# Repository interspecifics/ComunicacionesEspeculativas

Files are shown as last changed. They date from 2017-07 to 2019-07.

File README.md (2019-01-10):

# ComunicacionesEspeculativas
Es un proyecto basado en una máquina que es capaz de observar y aprender de
microorganismos para crear un score audiovisual a partir de los patrones que encuentre en su comportamiento. Este proyecto se apoya en la creación de una inteligencia artificial, la cual reconoce comportamientos organizados reiterativos en cultivos biológicos y los transforma en eventos que dota de una gestualidad audiovisual específica con el fin de lograr una composición autogenerativa que responde a las lógicas de decisión que esta inteligencia construye con el tiempo. 

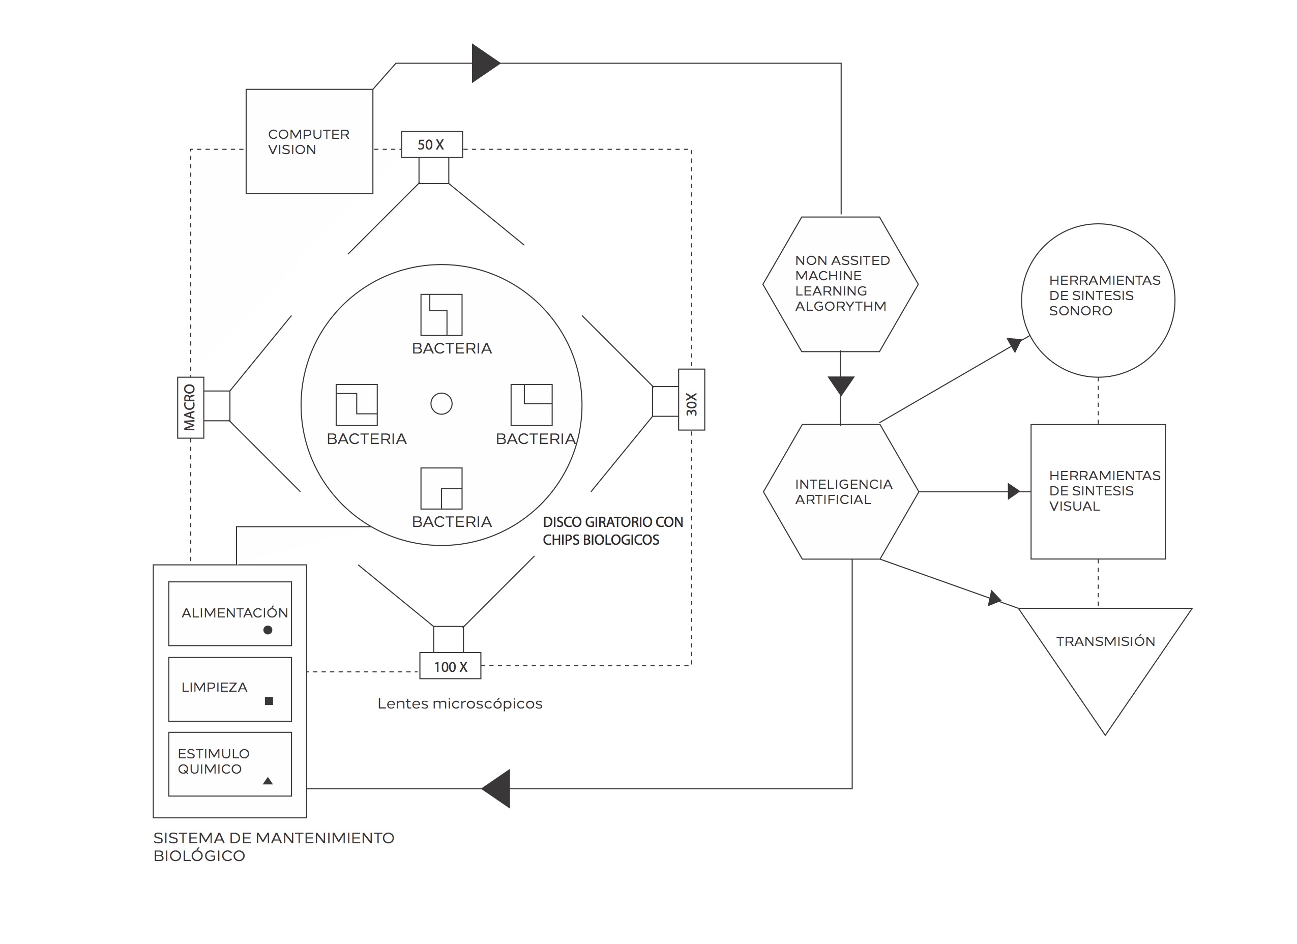
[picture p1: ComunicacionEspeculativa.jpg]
the system


## Instalación CV2.4.9 en Mac
1 - Instalar brew http://brew.sh/

>brew tap homebrew/science

>brew install opencv

## Instalación CV2 en la raspberry

seguir el tutorial que se encuentra aquí:
https://www.pyimagesearch.com/2015/02/23/install-opencv-and-python-on-your-raspberry-pi-2-and-b/

## Instalación netatalk

1- Installation:

>sudo apt-get update

>sudo apt-get install netatalk

2- Configuration

**Stop the service:**

>sudo /etc/init.d/netatalk stop

**Open the configuration file:**

>sudo nano /etc/netatalk/AppleVolumes.default

**You can edit the mount folder if you wish or leave the default value:**

>~/ "Home Directory"

**Start the service again**

>sudo /etc/init.d/netatalk start

## Configurar USB como storage local

**1 - To mount a USB drive:**

>sudo mkdir /mnt/usbdrive

>sudo mount /dev/sda1 /mnt/usbdrive

>ls /mnt/usbdrive

**2 - To list your file systems:**

>sudo fdisk -l

>sudo mount -l

>df -h

**3- Before disconnecting a USB drive:**

>sudo umount /dev/sda1

**4- Format a drive to EXT4**

>sudo mkfs.ext4 /dev/sda1 -L untitled

**5- Create a mount point**

>sudo mkdir /mnt/usbdrive

**6- Check the dev directory

>/dev/sd*

**7- To mount the drive to your mount point ‘usbdrive‘.

>sudo mount /dev/sda1 /mnt/usbdrive

**8- Disconnect / Unmount A Drive**

>sudo umount /dev/sda1

## Biotracker XY

Para la construcción de biotracker xy es necesario la impresión de la piezas que se encuentran aquí :

https://github.com/interspecifics/ComunicacionesEspeculativas/tree/master/Impresion%203d%20XY

Biotracker

Biotracker

## Controllers 

Actualmente existe dos placas electronicas para el control de los dos dispositivos disponibles el Microscopio Z y el Biotracker X/Y

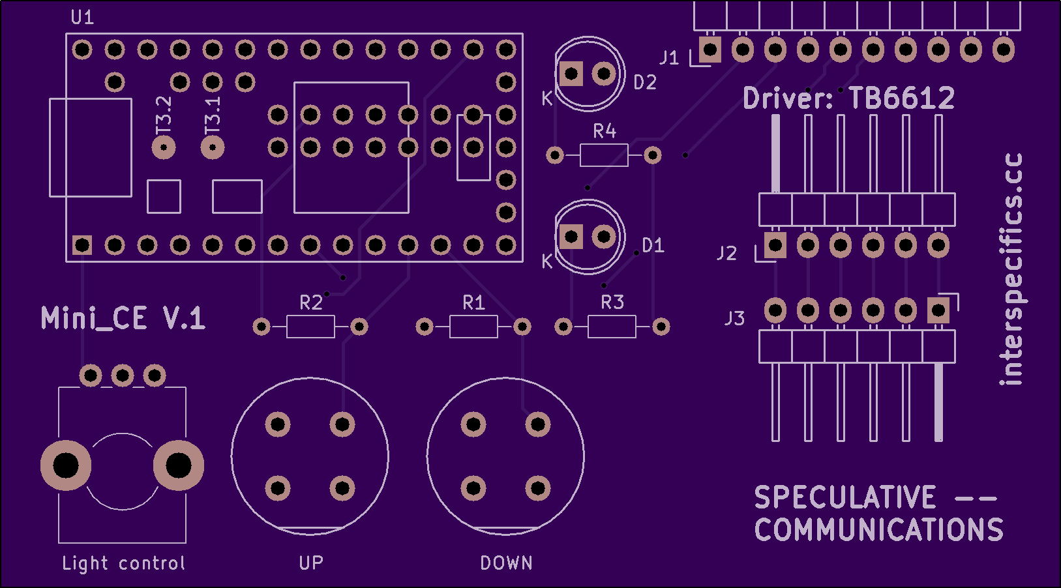
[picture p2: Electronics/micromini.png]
microminiz


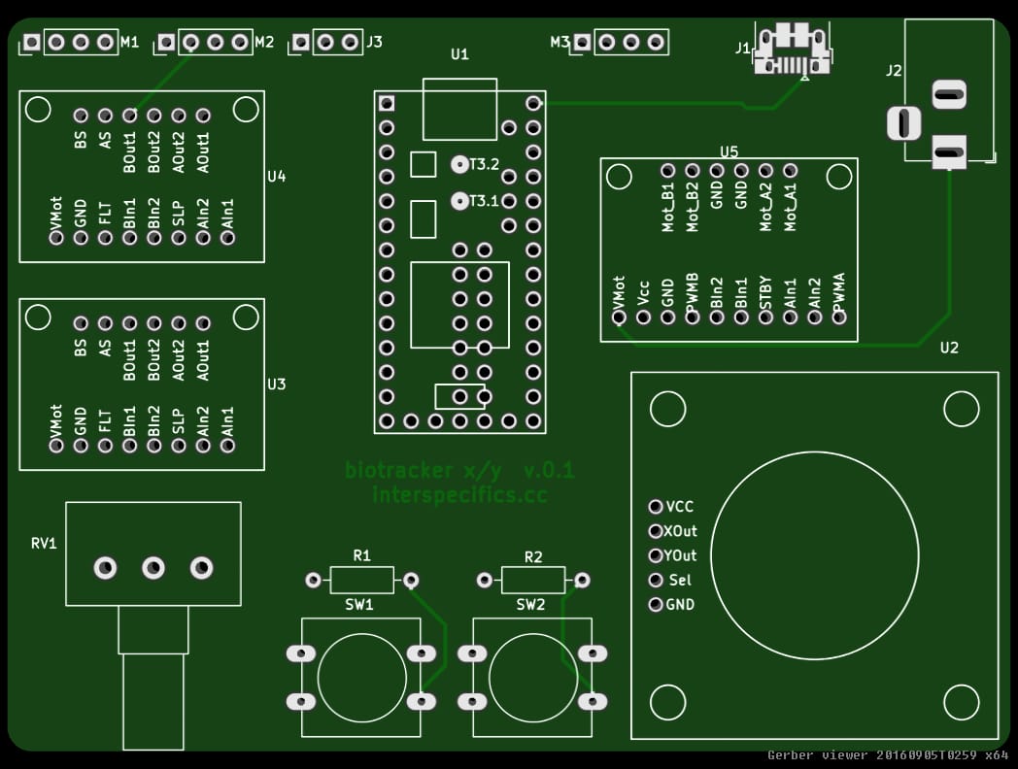
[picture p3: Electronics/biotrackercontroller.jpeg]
Biotracker Controller


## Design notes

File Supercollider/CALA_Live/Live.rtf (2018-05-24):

1. Drone
2. Multidrone
3. Saturn cluster Loop Flutes con noise//TUBES
4. Toplogical sonando los que están arriba
5. Saturno grande lead flute
6. Free swimmers
7. Big bass
8. Infinite energy
9. Saturn cluster Loop Flutes con harmonic
10. Collision detected
11. Salir
Luz cristal off

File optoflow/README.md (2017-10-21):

# CE_probe

====================================================================

# Para usar la pycam como cv2.videoCapture(0) hay que ejecutar

sudo apt-get install autoconf gettext libtool libjpeg62-dev

sudo apt-get install autoconf

sudo apt-get install v4l-utils

sudo modprobe bcm2835-v4l2

# Cambiar resolucion para hacer una captura [parece que no se mantiene]

v4l2-ctl --set-fmt-video=width=1920,height=1080,pixelformat=3

v4l2-ctl --stream-mmap=3 --stream-count=1 --stream-to=test1.jpg

# Llamar la herramienta desde otro proceso

import subprocess

subprocess.Popen(" python ce_ff_02.py -v \"0\" -s \"False\" -w \"False\"", shell=True)

# Ejecutar con distintias opciones

>python ce_ff_06.py -v "./TL6.mp4" -w "False" -s "True" -c "True"

>python ce_ff_06.py -v "./TL9.mp4" -w "True" -s "True" -c "False" -o "./TL9_out"

>python ce_ff_06.py -v "./videos/TL13.mp4" -w "False" -s "True" -n "True" -c "True"

>python ce_ff_07.py -v "./TL3.mp4" -w "False" -s "False" -n "True" -c "True" -d "True" -r "192.168.1.25" -p "57120"

====================================================================

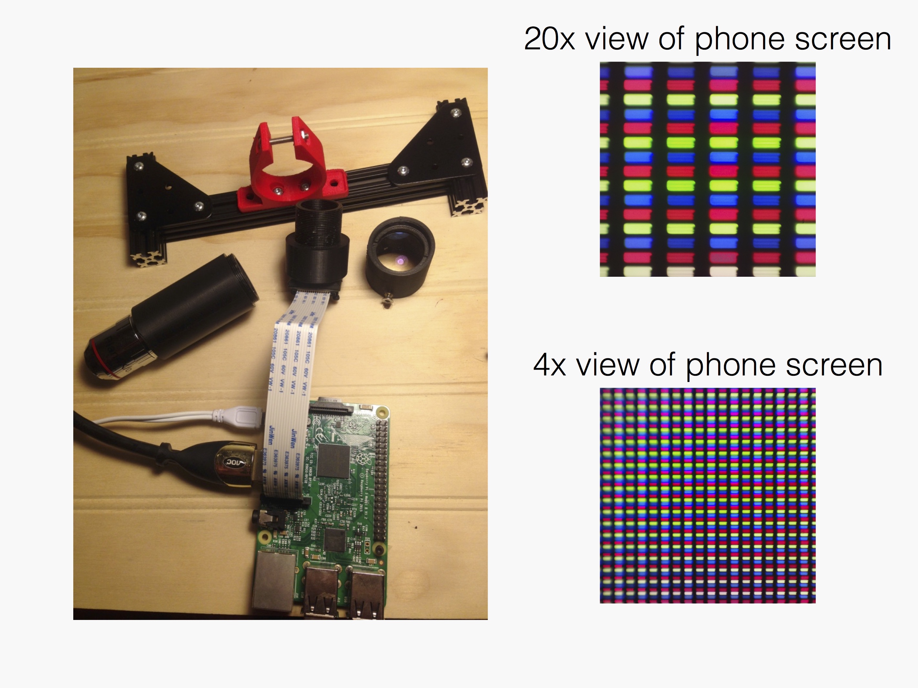
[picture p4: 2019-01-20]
3D_files/CE_optics/optical tube 2 fig.jpg

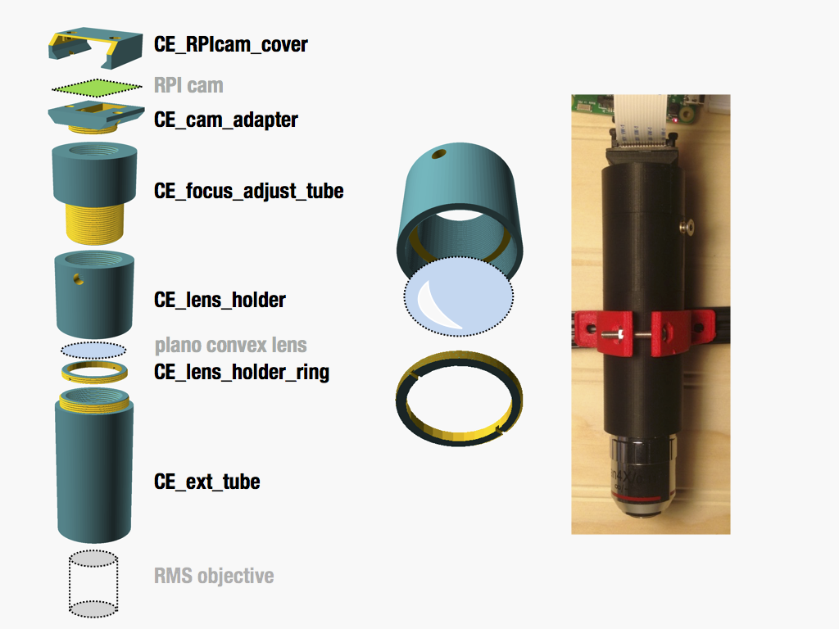
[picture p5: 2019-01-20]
3D_files/CE_optics/optical tube fig.png

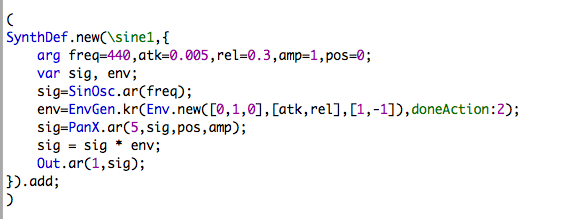
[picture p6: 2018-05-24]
Supercollider/CALA_Live/Screen Shot 2018-05-01 at 9.21.22 AM.png

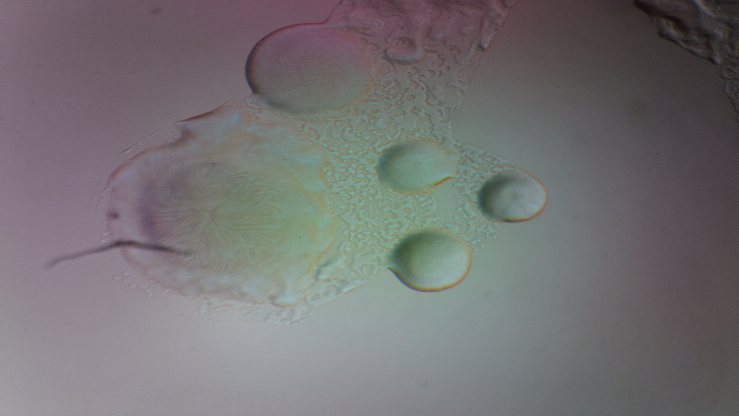
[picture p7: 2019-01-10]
Dataservice/CE_server/v05.png

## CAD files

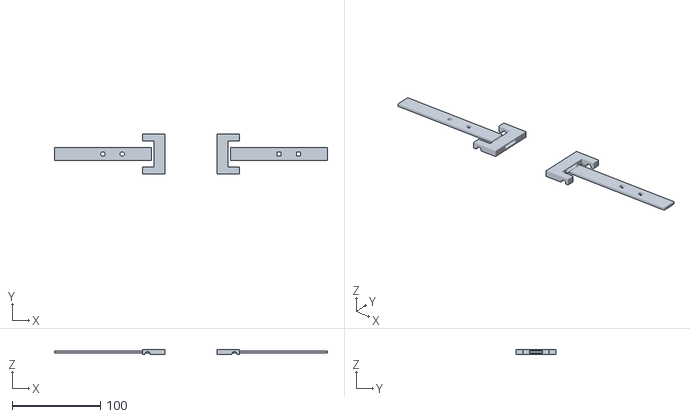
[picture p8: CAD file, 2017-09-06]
3D_files/CE_LEDholderV2.stl
310.0 x 45.0 x 6.00

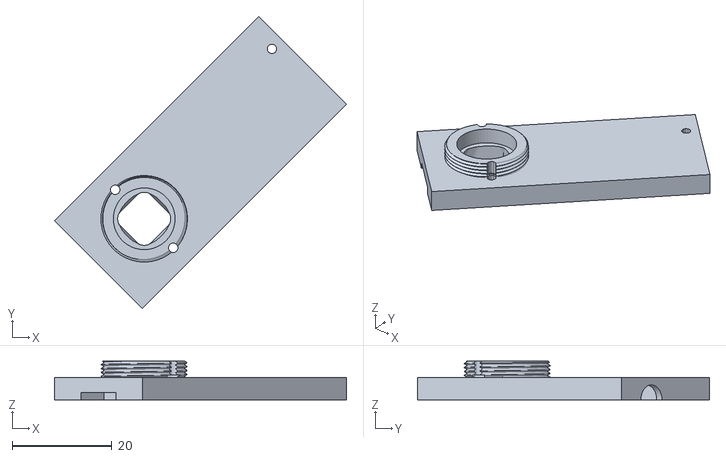
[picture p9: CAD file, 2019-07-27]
3D_files/CE_optics/CE_c270_camera_adapter.stl
58.7 x 58.7 x 7.78

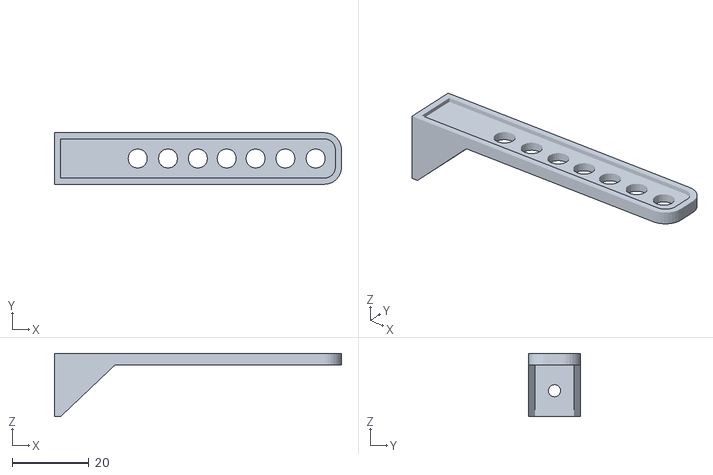
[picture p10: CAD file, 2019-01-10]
Impresion 3d XY/Fijacion LED/LED Inferior soporte horizontal.stl
75.0 x 13.5 x 16.5

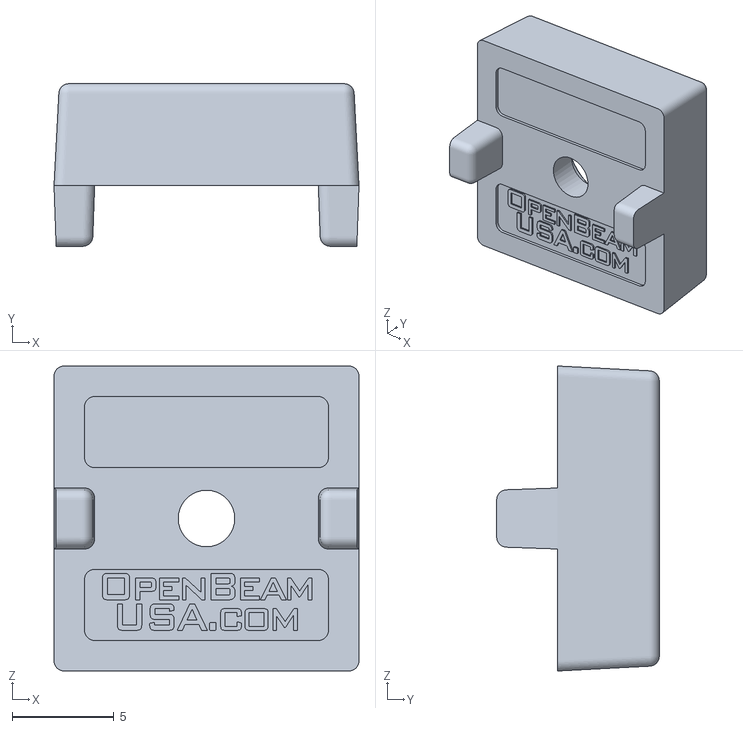
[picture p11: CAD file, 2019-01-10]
Impresion 3d XY/OpenBeam/Feet.STL
15.0 x 8.00 x 15.0

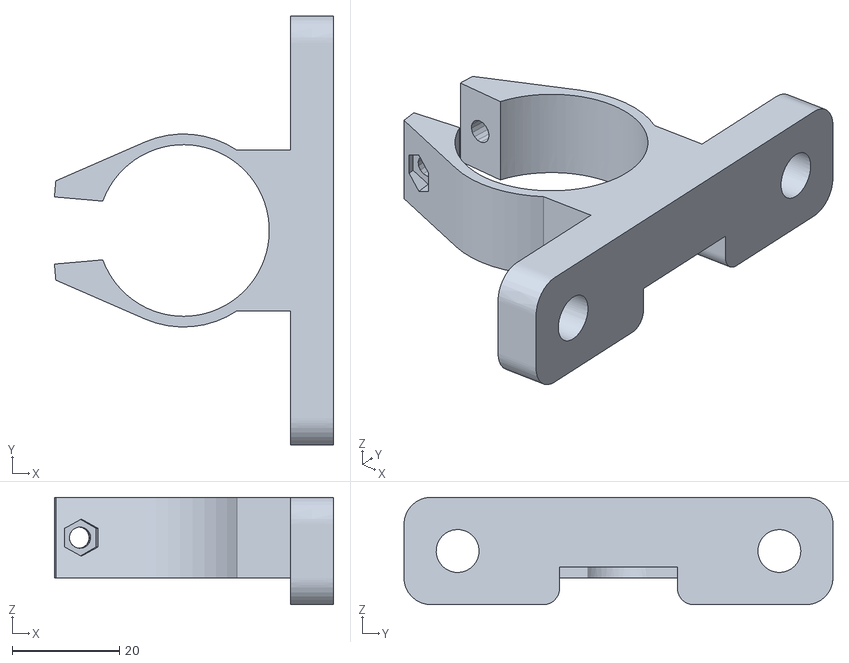
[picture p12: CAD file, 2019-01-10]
Impresion 3d XY/XY/Eje Y lente.stl
52.1 x 80.0 x 20.0

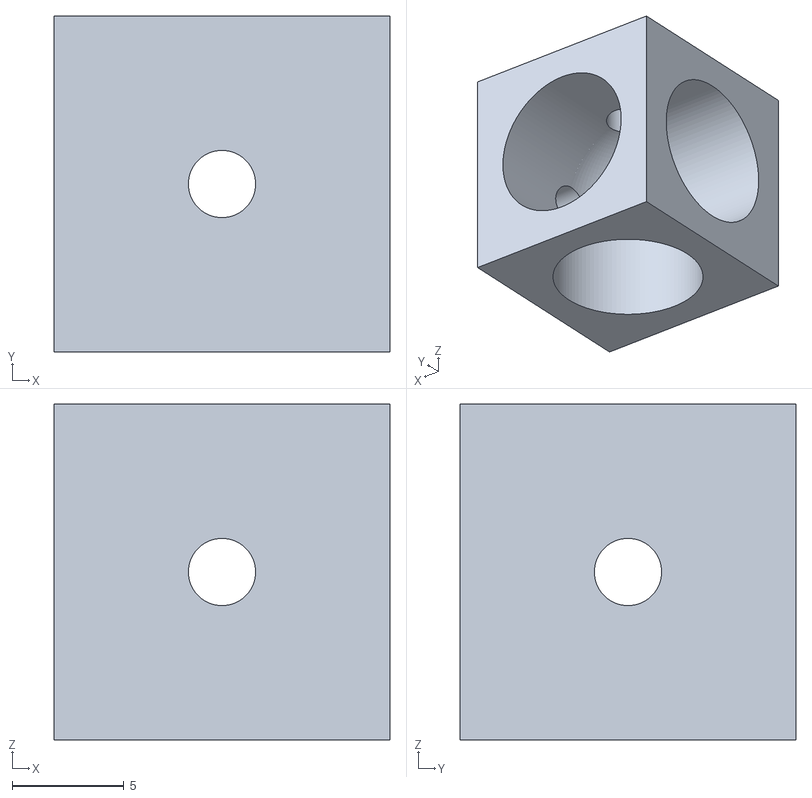
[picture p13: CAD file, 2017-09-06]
3D_files/CE_corner_openbeam.stl
15.0 x 15.0 x 15.0

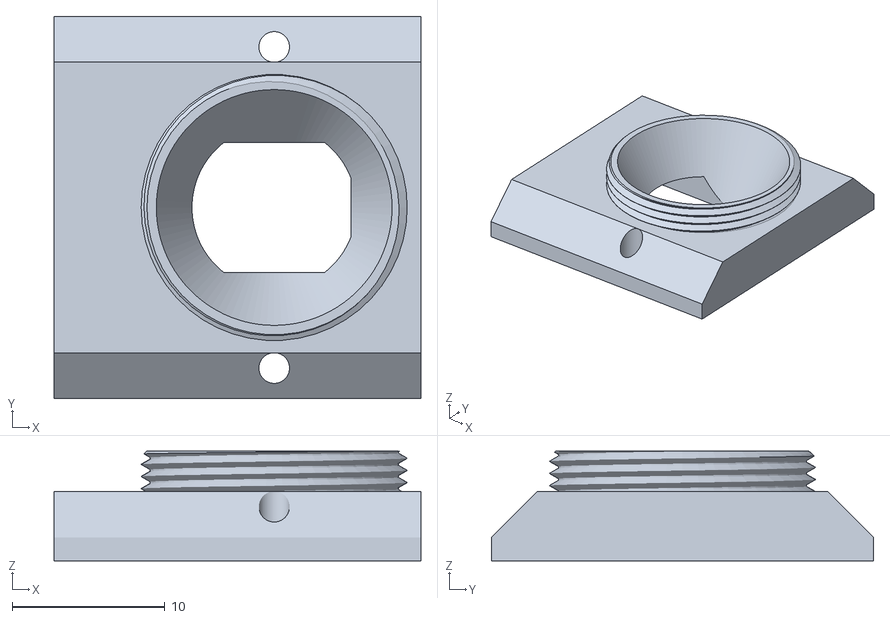
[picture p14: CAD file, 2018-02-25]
3D_files/CE_optics/CE_cam_adapter.stl
24.0 x 25.0 x 7.19

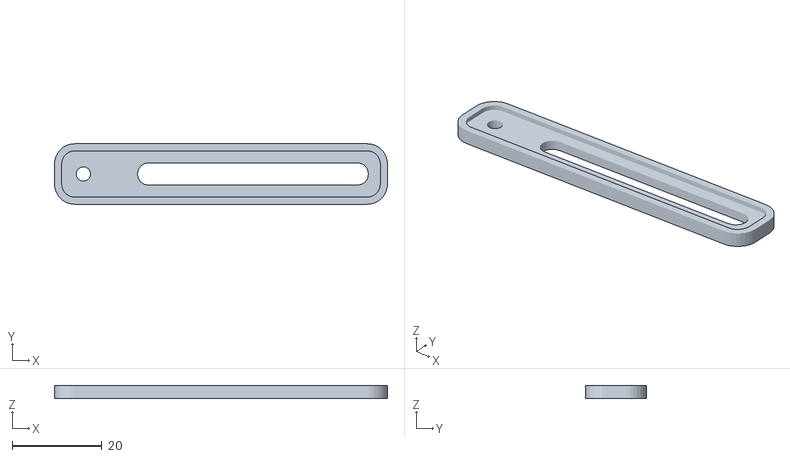
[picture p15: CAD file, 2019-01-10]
Impresion 3d XY/Fijacion LED/LED inferior fijacion vertical.stl
74.2 x 13.5 x 3.00

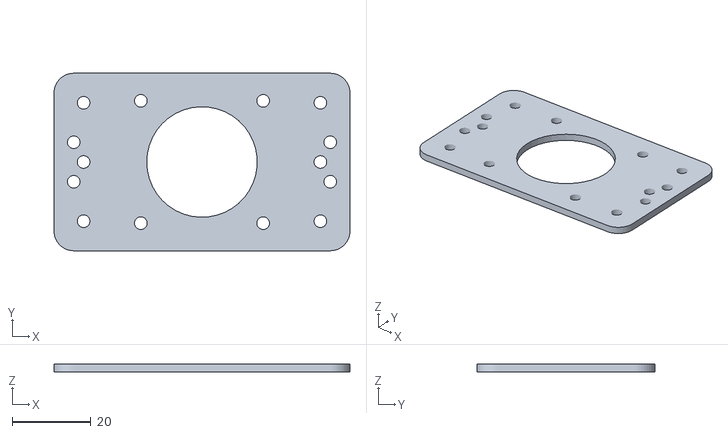
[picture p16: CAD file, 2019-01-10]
Impresion 3d XY/OpenBeam/NEMA_17_Motor_Mount.STL
75.0 x 45.0 x 2.03

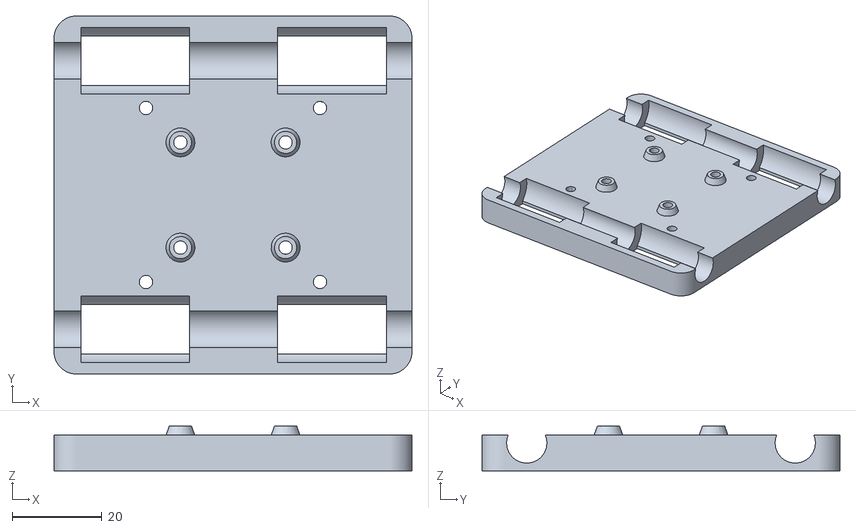
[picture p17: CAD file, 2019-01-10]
Impresion 3d XY/XY/Base inferior.stl
80.0 x 80.0 x 10.0

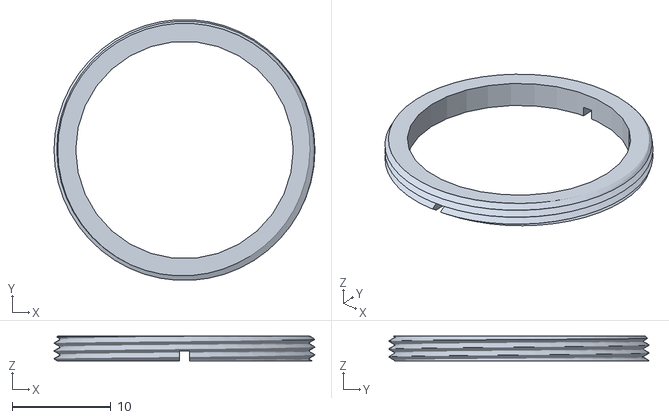
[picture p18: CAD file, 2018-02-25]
3D_files/CE_optics/CE_lens_holder_ring.stl
26.4 x 26.3 x 2.50

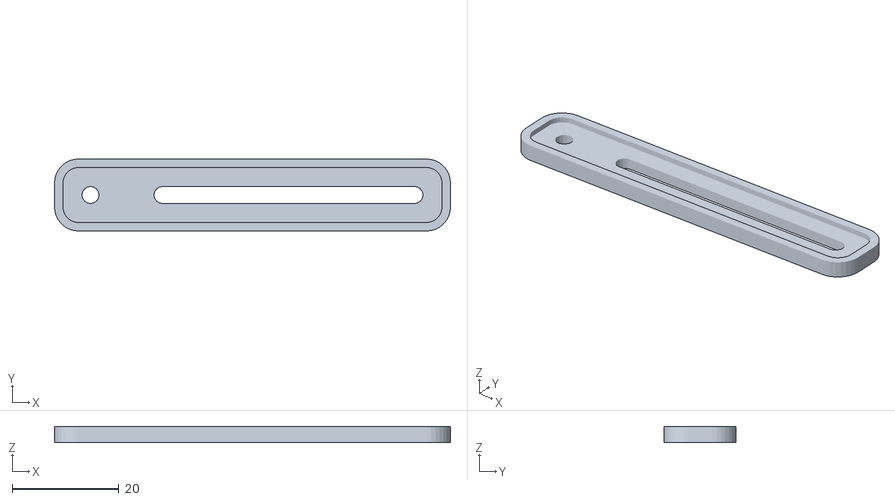
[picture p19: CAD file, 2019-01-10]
Impresion 3d XY/Fijacion LED/LED lateral.stl
74.2 x 13.5 x 3.00

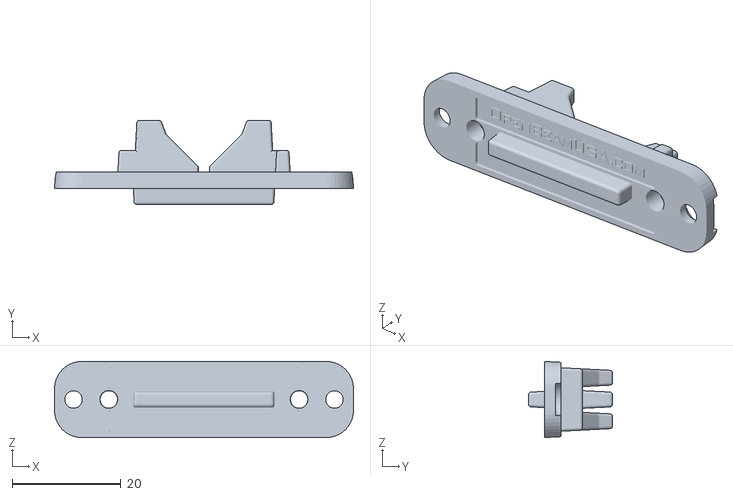
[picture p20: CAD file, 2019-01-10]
Impresion 3d XY/OpenBeam/Shaft Clamp.STL
55.0 x 15.5 x 14.0

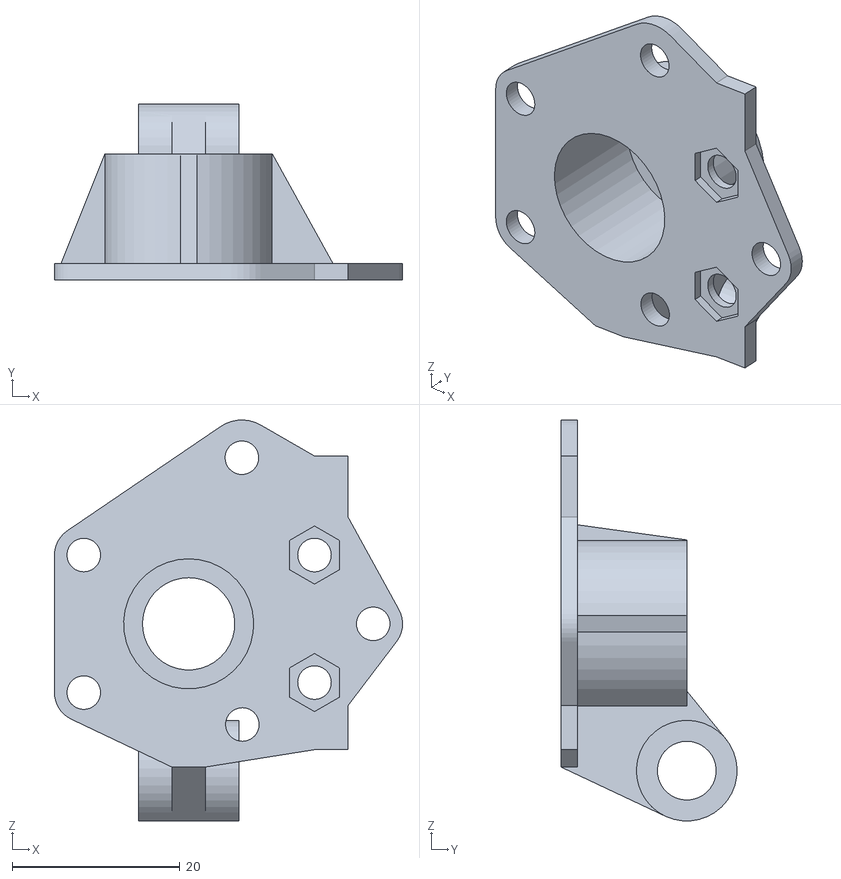
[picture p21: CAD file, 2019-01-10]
Impresion 3d XY/Stage/Bearing Mount Left Top.STL
41.5 x 21.0 x 47.8

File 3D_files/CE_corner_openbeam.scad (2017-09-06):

/*
 Basic corner piece for open beam by Comunicaciones Especulativas 2017 (CC BY 4.0; https://creativecommons.org/licenses/by/4.0/) 
 http://interspecifics.cc/comunicacionesespeculativas/
 
 To use/modify this in your own projects add the following lines to your code:
 use <path_to_this_file/CE_corner_openbeam.scad>
 OB_corner(dim);
 */

// only change dimensions here
OB_corner(3); //2 for 2D joint and 3 for 3D joint
 
// module
beam=15;
screw=3;
$fn=100;
fudge=0.05; // to fix error in rendering leaving thin wall...help me if you better!
dim=3; //2 for 2D joint and 3 for 3D joint
module OB_corner(dim) {
    difference() {
    cube(beam, center=true);
        sphere(r=(beam/2)*0.7, center=true);
            if(dim>2)
                for(i = [ [0,0,0],[90,0,0],[0,90,0]]){
                rotate(i)
                    union() {
                        cylinder(r=screw/2,h=(beam/2)+fudge);
                            translate([0,0,-(beam/2+fudge)]) 
                                cylinder(r=(beam/2)*0.7,h=beam/2);}}
            else
                for(i = [ [0,0,0],[90,0,0]]) {
                 rotate(i)
                    union() {
                        cylinder(r=screw/2,h=(beam/2)+fudge);
                            translate([0,0,-(beam/2+fudge)]) 
                                cylinder(r=(beam/2)*0.7,h=beam/2);}}
                            
    }
}

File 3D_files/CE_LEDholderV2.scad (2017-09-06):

/*
 LED holder for microscope by Comunicaciones Especulativas 2017 (CC BY 4.0; https://creativecommons.org/licenses/by/4.0/) 
 http://interspecifics.cc/comunicacionesespeculativas/
 
 To use/modify this in your own projects add the following lines to your code:
 use <path_to_this_file/CE_LEDholderV2.scad>
 holder(); 
 central();
 */

dist_bars=102;// distance between horizontal stage bars
threaded_bar=5.7;//thickness of horizontal stage bars
LED=5; // standard 5mm LED
width=30;
length=110;// length of the central bar holding the LED
thickness=3;
fit=0.5; // to play with printing resolution and make pieces fit nicely
ADA=4.6; // adafruit LED
hole_style= 2; // 0= normal LED, 1= Adafruit square single RGB LED; 2=both

module holder() { // holders to stage rods
    
difference() {
    cube([length,width*1.5,thickness*2], center=true);
             union() color("Yellow") {
                 cube([length-width*1.7,width*1.5,thickness*2], center=true);
                 cube([length*0.85,width/2,thickness], center=true);
             }
    
    rotate([90,0,0]) color("Red"){
        translate([(length/2-threaded_bar),-(thickness*0.8),-(width*1.5)/2]) {
                cylinder(r=threaded_bar/2,h=width*1.5, $fn=100);  
    }
}
    
    rotate([90,0,0]) color("Blue"){
        translate([-(length/2-threaded_bar),-(thickness*0.8),-(width*1.5)/2]) {
                cylinder(r=threaded_bar/2,h=width*1.5, $fn=100);  
    }
}
    translate([(length/2)-threaded_bar,0,0]) color("Green"){
    cube([width/2,width,thickness*2], center=true);
}
    translate([-((length/2)-threaded_bar),0,0]) color("Red"){
    cube([width/2,width,thickness*2], center=true);
}
}
}

module CentralLED() { // for normal LED
    difference() {
    cube([length,(width/2)-fit,thickness-fit], center=true);
            translate([0,0,-thickness*2]) 
               cylinder(r=LED/2,h=thickness*3, $fn=100);
        translate([length*0.2,0,-thickness*2]) 
               cylinder(r=LED/2,h=thickness*3, $fn=100);
    }
} 

module CentralADA() { //for Adafruit RGB square single LED
    difference() {
    cube([length,(width/2)-fit,thickness-fit], center=true);
               cube([ADA,ADA,ADA], center=true);
         translate([length*0.2,0,0]) 
              cube([ADA,ADA,ADA], center=true);
}
}

module central(){
    if(hole_style == 0) {
			translate([-100,0,0]) { CentralLED();} //normal LED
	} else if(hole_style == 1) {
			translate([100,0,0]) { CentralADA();} //Adafruit square LED
	}
        else if(hole_style == 2) {
			translate([100,0,0]) { CentralADA(); } translate([-100,0,0])  CentralLED();} // print both 
    }

holder(); 
central();


	
        
        

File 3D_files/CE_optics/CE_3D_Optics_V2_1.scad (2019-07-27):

/*
This is part of the project Comunicaciones Especulativas: http://interspecifics.cc/comunicacionesespeculativas/ and https://osf.io/c542q/

This file creates a 3D printed version of the optical pieces used by Alexandre Kabla and his team for the openlabtools microscope (http://openlabtools.eng.cam.ac.uk/Instruments/Microscope/Optics/)
We used:

1- <picam_2_push_fit.scad> from  OpenFlexure Microscope: Raspberry Pi Camera v2 push-fit mount (c) Richard Bowman, January 2016 Released under the CERN Open Hardware License  

2- <threads.scad> from http://dkprojects.net/openscad-threads/

    english_thread is in inches that´s why all mmm values are divided by 25,4

    Normally one male thread fitting into another (e.g. housing a lens)  requires some extra mm in between. Normally this is done by reducing male by 3*corr (corr= 0.2mm). The only exception is at joints where an outsourced piece is hosted (e.g. lens). In this case, the corr is applied to the female.

All this code is licensed under the Creative Commons - Attribution  (CC BY 3.0)
Fernán Federici 2017

*/

use <threads.scad>
use <logitech_c270.scad>
include <picam_2_push_fit.scad>         




corr=0.2;// sometimes used for printing imperfections
sunny_space=6;
wall=2.5;
base_xy=16;
screw_d=21;//distance between screw holes
screw_r=2/2;
screw_hold_r=2;
M12_r=12/2;
mount_h = 10;
int_r=22/2;// internal r of cylinder according to edmund optics
RMS_r=(0.8*25.4)/2; //10,16 mmm of r for DIN (and JIS) objectives that uses RMS, this is about 20.3mm (with thread step of about 0.7mm).
tube_r=29.85/2;//external size
c_mount_r=25.4/2; //for 1 inch standard C-mount diameter
internal_lens_hol=26; //where the Comar lens stays
RMS_mount_h=6; 
c_mount_h=4;
M27_r=27/2; //M27 threads
lens_holder_male_len=3.5; //length of male cylinder end that goes inside top part and holds the lens against the notch of top part 
focus_reg_len=19;// thread for focus adjustment
M3_brass_push_h=4;//for M3 screws
M3_brass_push_w=4;//for M3 screws
tot_len_top=15+5+10+11.3+4;//total len of a single piece A
ext_bot_len=11.3+10+5;
aper_int_h=22.5; //h of internal space 
foc_adj_r=21.5/2;//width of thread for focus control
int_focal_corr_h=16;//total length to adjust focus without crashing to lens of top bottom piece
int_focal_corr_r=18/2;
lens_holder_pos=8.5; //distance of lens holder notch from bottom end of top part 
tot_len_focus_adjust_tube=4+15+16;//16mm to not crash the lens inside the top bottom part
tot_len_bottom=6+40+5;//total length of the ext_tube section
fluo_top_h=26;
pol_ring_h=10;
fluo_bottom_h=25;//ext_fluo_bottom height
sens_x=8.5;
filter_cube_x=40;
filter_cube_y=40;
filter_cube_z=24;
x_triangle=19;//to have hipotenuse of >25
y_triangle=19;//to have hipotenuse of >25
collimated_r=x_triangle/2-x_triangle*0.05;
M3_r=3/2;
M3_h=10;
joint_x=5;
joint_y=5;
joint_z=2;
filter_cube_top_z=10;  
extra_doublet=10; 
MM_h=5;
base_h=6;
mounting_hole_x = 8.25;
$fn=60;


/* The organization of each module can be found here: http://interspecifics.cc/comunicacionesespeculativas/2018/03/09/tutorial-7-codigo-openscad-para-tubo-optico/

The order of modules - from top to bottom - is:

RPIcam_cover();
cam_adapter();
focus_adjust_tube();
lens_holder_ring();
CE_ext_tube();

*/


//RPIcam_cover();
//cam_adapter();
//cam_adapter_v2();
//focus_adjust_tube();
//lens_holder(); // or lens_holder_V2()
//lens_holder_ring();
//ext_tube(); // or ext_fluo_top() and ext_fluo_bottom() is using polarizers/filters
//camera_mount_FF();
//CE_c270();
lens_holderV2();   //this one is to use a achromat doublet for the 100X (the ones used with yeast samples)



module RPIcam_cover(){
    fit_corr=1;//makes it bigger to fit and avoid damaging the PCB
    
    // A cover for the camera PCB, slips over the bottom of the camera
    // mount.  This version should be compatible with v1 and v2 of the board
    start_y=-12+2.4;//-3.25;
    l=-start_y+12+2.4; //we start just after the socket and finish at 
    //the end of the board - this is that distance!
    difference(){
        union(){
            //base
            translate([-15,start_y,-4.3]) cube([25+5,l,4.3+d]);
            //grippers
            reflect([1,0,0]) translate([-15,start_y,fit_corr]){
                translate([0,0,-fit_corr]) cube([2,l,4.5-d]);
                hull(){
                    translate([0,0,1.5]) cube([2,l,3]);
                    translate([0,0,4]) cube([2+2.5,l,0.5]);
                }
            }
        }
        translate([0,0,-1]) picam2_pcb_bottom();
        //chamfer the connector edge for ease of access
        translate([-999,start_y,0]) rotate([-135,0,0]) cube([9999,999,999]);
    }
} 
 
module cam_adapter(){

difference(){
union(){ 
       rotate([ 0.00, 0.00, 45.00 ])camera_mount_FF();
   color("lightblue") english_thread (diameter=((int_focal_corr_r*2)-(3*corr))/25.4, threads_per_inch=32, length=M3_brass_push_h/1.5/25.4,internal=false, n_starts=1, thread_size=-1, groove=true,square=false, rectangle=0, angle=30, taper=0, leadin=1);
}
   cylinder(r1=sens_x/2,r2=sens_x,h=sens_x, center=true,$fn=100);
}}
  


module cam_adapter_v2(){
    difference() {
                union() {
                    //threaded part
                    translate([0,0,M3_brass_push_h/1.5 + base_h-corr])       
   color("lightblue") english_thread (diameter=((int_focal_corr_r*2)-(3*corr))/25.4, threads_per_inch=32, length=(M3_brass_push_h/1.5+corr)/25.4,internal=false, n_starts=1, thread_size=-1, groove=true,square=false, rectangle=0, angle=30, taper=0, leadin=1);
				translate([0,sunny_space/2,base_h/2+wall/2])
					color("green")  cube([base_xy, base_xy+sunny_space, base_h+wall], center = true);
				color("Red") translate([screw_d/2, 0, 0])
					cylinder(r = screw_hold_r, h = base_h/2);
				color("Red") translate(-[screw_d/2, 0, 0])
					cylinder(r = screw_hold_r, h = base_h/2);
				color("Red") translate([0,0,base_h/2/2])
						cube([screw_d, 4, base_h/2], center = true);
		}
		translate([0,sunny_space/2,base_h/2-wall])
			color("blue") cube([base_xy - wall, base_xy+sunny_space - wall, base_h*2], center = true);
		translate([screw_d/2, 0, 0])
			cylinder(r = screw_r, h = base_h);
		translate([-screw_d/2, 0, 0])
			cylinder(r = screw_r, h = base_h);
	
        translate([0, 0, base_h-corr])     cylinder(d=((M12_r*2)+(corr*2)), h=mount_h*2);
	}}
  
//    translate([ 0.00, 0.00, 10.00 ]) cam_adapter_v2();
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

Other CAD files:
Impresion 3d XY/Stage/Bearing Mount Right Top.stl
Impresion 3d XY/XY/Eje X 2.stl
3D_files/CE_optics/CE_RPIcam_cover.stl
Impresion 3d XY/OpenBeam/L Bracket.STL
3D_files/CE_optics/logitech_c270.scad
3D_files/CE_optics/picam_2_push_fit.scad
3D_files/CE_optics/threads.scad
3D_files/CE_optics/utilities.scad
3D_files/CE_optics/utilitiesRB.scad
Impresion 3d XY/OpenBeam/T Bracket.STL
Impresion 3d XY/Stage/Bearing Mount Left Bottom.STL
Impresion 3d XY/Stage/Bearing Mount Right Bottom.STL
Impresion 3d XY/Stage/Front stage Mount.stl
Impresion 3d XY/Stage/Thread Nut Mount Bottom.STL
Impresion 3d XY/Stage/Thread Nut Mount Top.STL
Impresion 3d XY/XY/Base superior.stl
Impresion 3d XY/XY/Eje X 1.stl
Impresion 3d XY/XY/Eje Y Tensor.stl
Impresion 3d XY/XY/Eje Y trasero.stl

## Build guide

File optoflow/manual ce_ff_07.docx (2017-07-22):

[ce_ff_07.py]:

======================================

Comunicaciones Especulativas Flow Field v 0.7

Es un sistema para análisis de las secuencias de imágenes generadas por raspyLapse.

La herramienta usa la implementación del algoritmo de Lucas-Kanade[^1] de OpenCV[^2] para calcular un campo de flujo óptico a partir de la diferencia de dos imágenes sucesivas en el tiempo. Este campo de flujo es una representación, en un espacio de alta dimensionalidad del cambio ocurrido entre imágenes, que se acumulan para conformar un batch de datos de entrenamiento. Luego, se lleva a cabo un agrupamiento o clustering sobre estos datos usando la técnica KMeans[^3], que busca los patrones de regularidad entre estos vectores y los agrupa según la semejanza o diferencias de su contenido. La herramienta puede producir un stream de imágenes como salida y almacena en carpetas los modelos y datos que obtiene en cada ejecución. Finalmente, también permite cargar un modelo de agrupamiento antes entrenado y generar un stream de datos OSC a partir del análisis y clasificación en tiempo real.

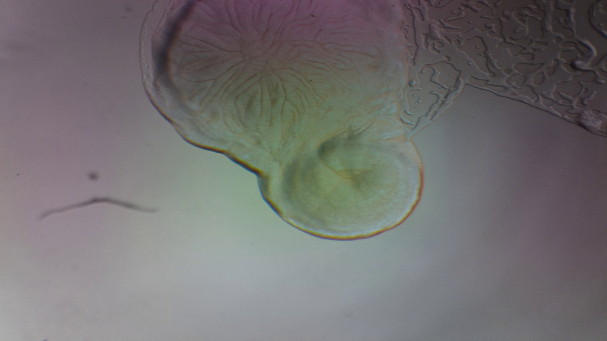
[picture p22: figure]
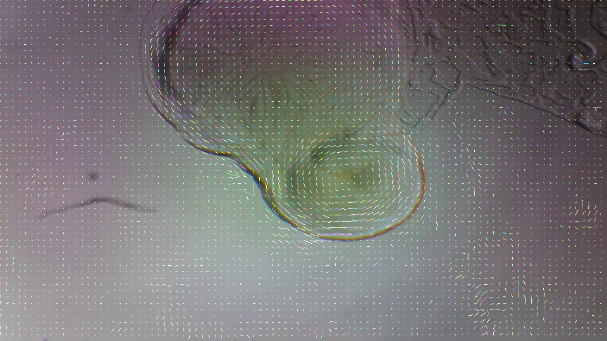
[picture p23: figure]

Fig:1.a Frame 84 del timelapse TL09 | Fig:1.b Con vectores de movimiento sobrepuestos

La herramienta acepta distintos parámetros de configuración para habilitar y deshabilitar etapas o funciones del proceso. La lista completa de argumentos que acepta en la actual versión 0.7 es:

Input folder path :: "-i", "--in-dir", default="./imgs_in" :: ruta del directorio donde se encuentran las imágenes de entrada, cuando no se usa el parámetro “-v”

Output folder path :: "-o", "--out-dir", default="./imgs_out" :: ruta del directorio para escribir imágenes de salida, cuando se usa el parámetro “-w”

Video Input path :: "-v", "--video" :: ruta del archivo de video de entrada, si se especifica el valor “0” el programa usará la webcam como stream de video

Enable show :: "-s", "--show", default="False" :: habilita el despliegue de información en video, desabilitada por defecto para funcionar por conexión remota

Enable write output files :: "-w", "--write", default="True" :: si está habilitada, guarda cada frame con las flechas del campo de flujo o direcciones discretas en el folder de “-o”

Model file path :: "-m", "--model", default="./models/kmeans_1500555372.cpk" :: carga el archivo indicado como modelo para asignar una etiqueta de grupo a cada nuevo frame

Canny detector enable :: "-n", "--canny", default="False" :: Si está habilitado, usa el algoritmo de detección de bordes para mejorar el contraste y detección de movimiento

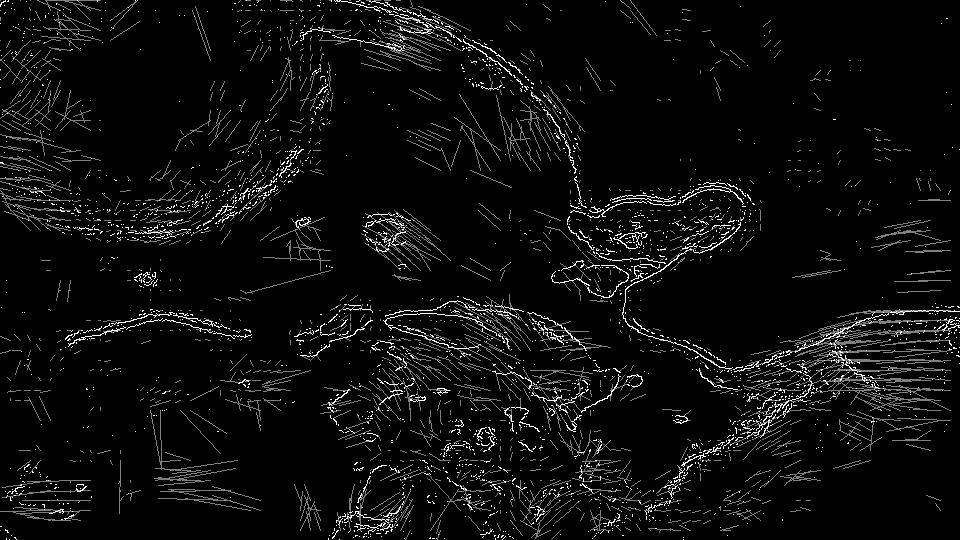
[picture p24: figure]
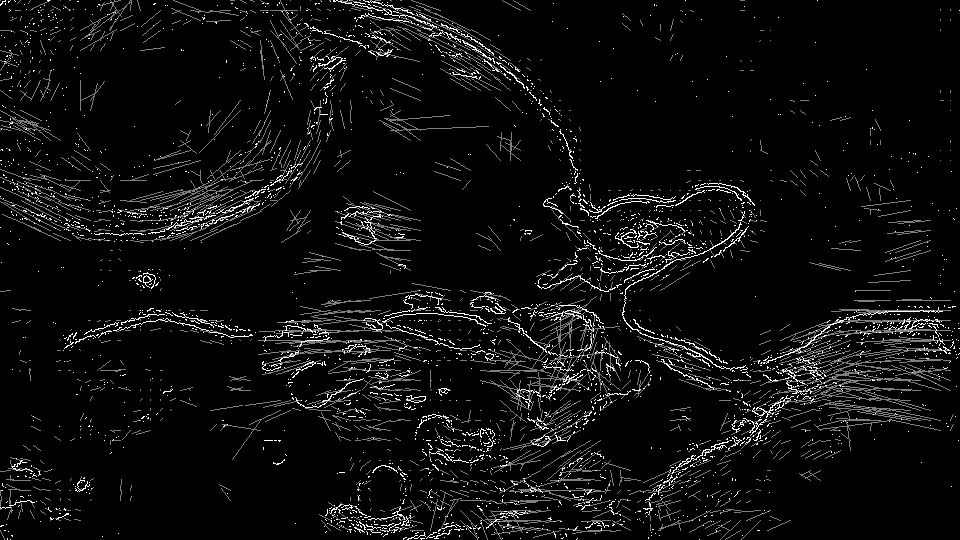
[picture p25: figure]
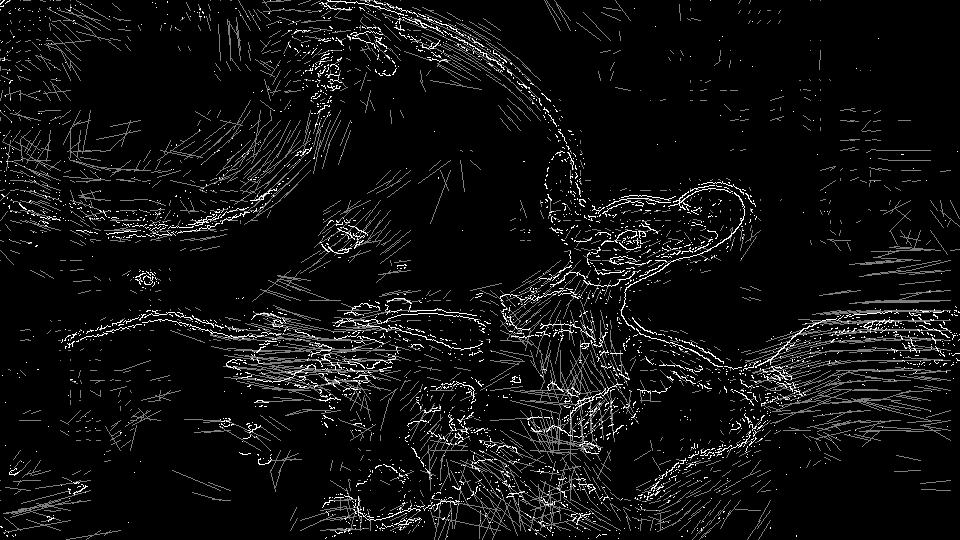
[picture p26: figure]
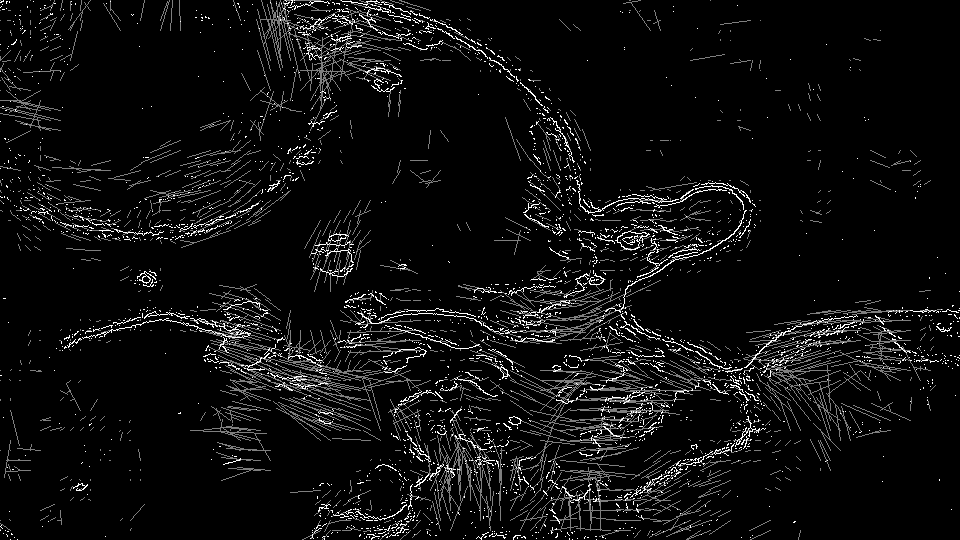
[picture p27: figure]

Fig 2: Frames 18[UL], 19[UR], 20[DL], 21[DR] con Canny edge detector habilitado

OSC stream enable :: "-c", "--osc", default="False" :: habilita la salida de mensajes OSC

Receiver IP address :: "-r", "--receiver-ip", default="192.168.1.255" :: dirección IP del receptor

Receiver OSC port :: "-p", "--receiver-port", default="57120" :: puerto IP del receptour

Discrete direction flowfield enable :: "-d", "--direct", default="False" :: Cuando habilitado, discretiza la dirección del movimiento hacia los 5 rumbos cardinales: NESWZ; en otro caso proporciona el valor del ángulo de movimiento medido desde +X en el rango de [-PI, PI].

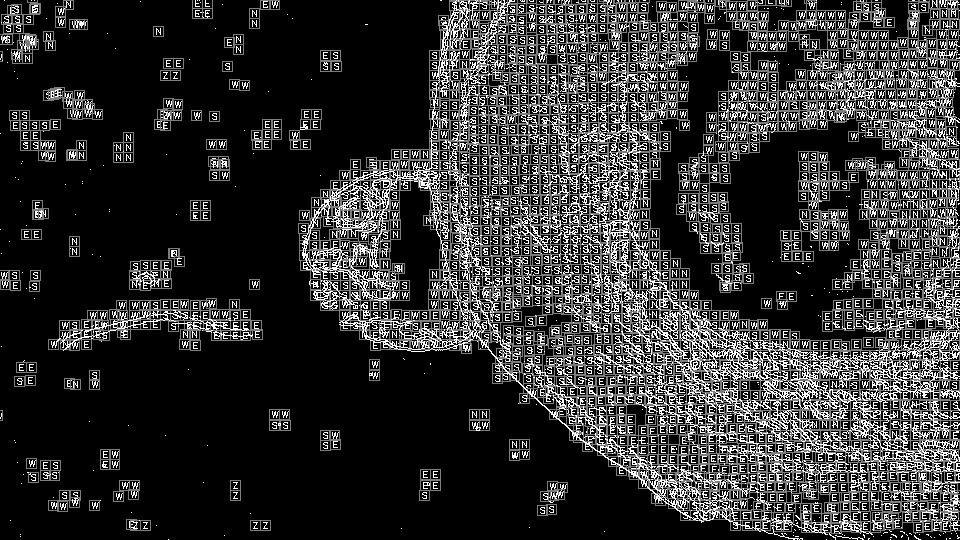
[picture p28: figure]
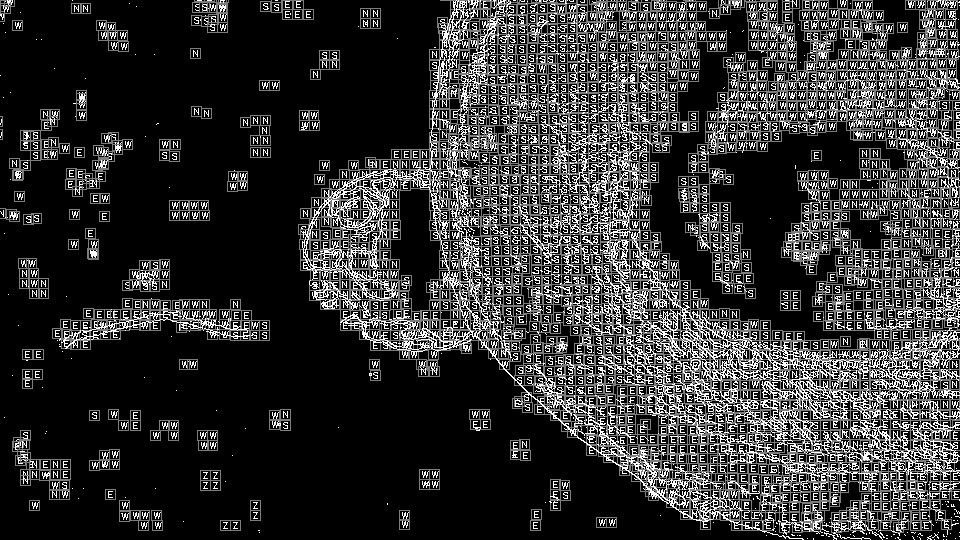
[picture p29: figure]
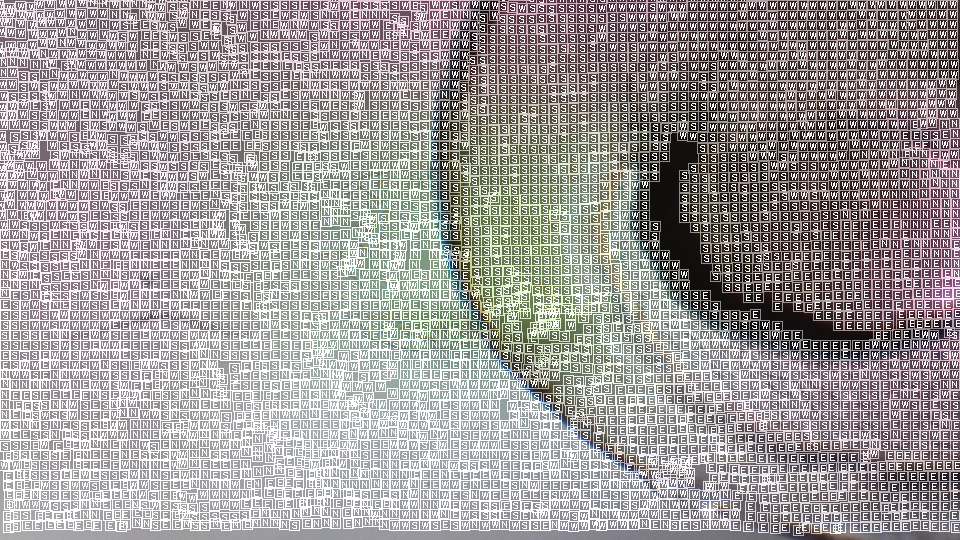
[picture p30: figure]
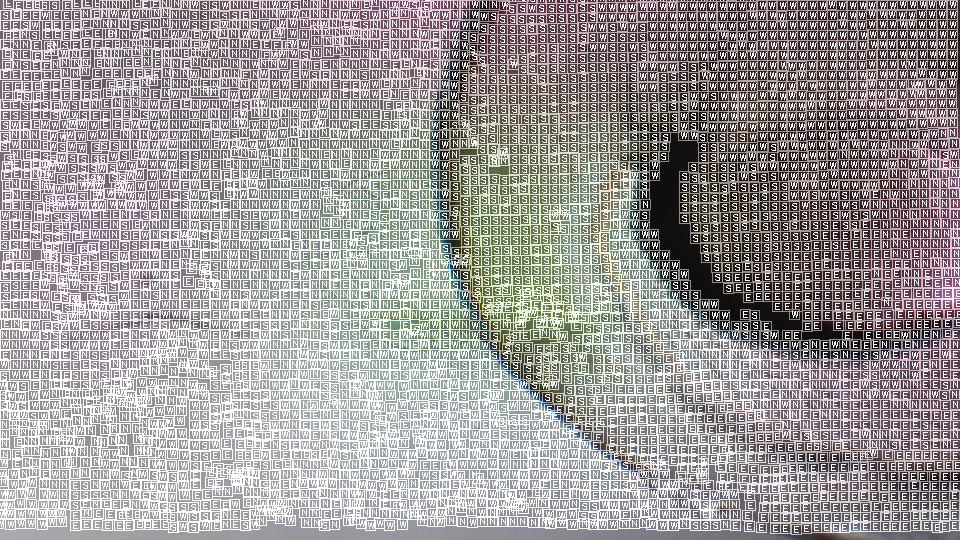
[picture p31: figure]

Fig 3: Diferencias en la detección de movimiento. Las imágenes superiores son frames sucesivos donde se han marcado únicamente los puntos con actividad luego de aplicar la detección de bordes. Las imágenes de abajo son la salida producida por las mismas imágenes, pero sin emplear la detección de bordes. Para estas capturas se habilitó también la discretización de direcciones, por lo que en cada casilla se indica con una pequeña letra la dirección del movimiento.

El script con la herramienta se ejecuta desde la términal y requiere una instalación con OpenCV (probado en las versiones 2.4 y 3.2), Python 2.7, y los paquetes numpy, scikit-learn >0.14, pyOSC, y cv2.

Ejemplos de uso:

1. Analiza el archivo TL6.mp4 en la carpeta local, no escribas archivos de salida pero sí muestra el proceso. Habilita el envío de OSC a la dirección por default:

$ python ce_ff_07.py -v "./TL6.mp4" -w "False" -s "True" -c "True"

2. Analiza el archivo TL9.mp4 en la subcarpeta /videos, escribe cada frame a la carpeta ./TL9_out, muestra el proceso y envía OSC a la dirección por default:

$ python ce_ff_4.py -v "./videos/TL9.mp4" -w "True" -s "True" -c "False" -o "./TL9_out"

3. Analiza el archivo TL3.mp4, no escribas archivos de salida, pero sí muestra el proceso, aplica el detector de bordes, también discretiza las direcciones y envía mensajes OSC a todas las instancias de supercollider conectadas a la red local (192.168.1.255::57120)

$ python ce_ff_07.py -v "./TL3.mp4" -w "False" -s "False" -n "True" -c "True" -d "True" -r "192.168.1.25" -p "57120"

[^1] http://www.inf.fu-berlin.de/inst/ag-ki/rojas_home/documents/tutorials/Lucas-Kanade2.pdf
[^2] http://docs.opencv.org/3.2.0/d7/d8b/tutorial_py_lucas_kanade.html
[^3] http://scikit-learn.org/stable/modules/generated/sklearn.cluster.KMeans.html

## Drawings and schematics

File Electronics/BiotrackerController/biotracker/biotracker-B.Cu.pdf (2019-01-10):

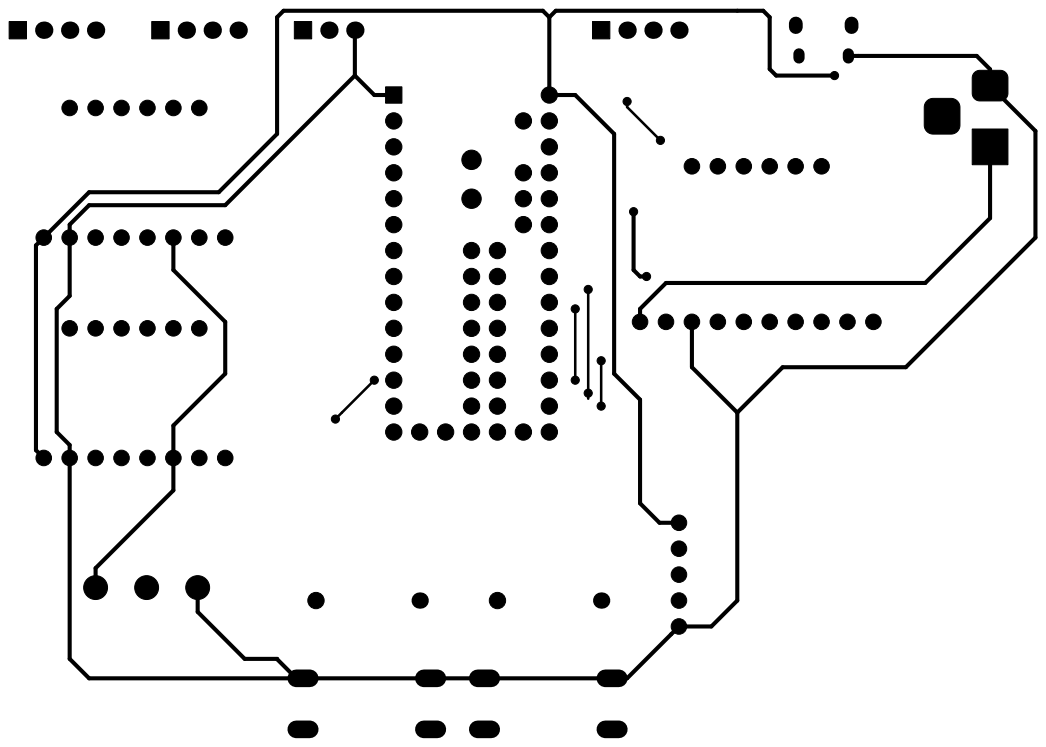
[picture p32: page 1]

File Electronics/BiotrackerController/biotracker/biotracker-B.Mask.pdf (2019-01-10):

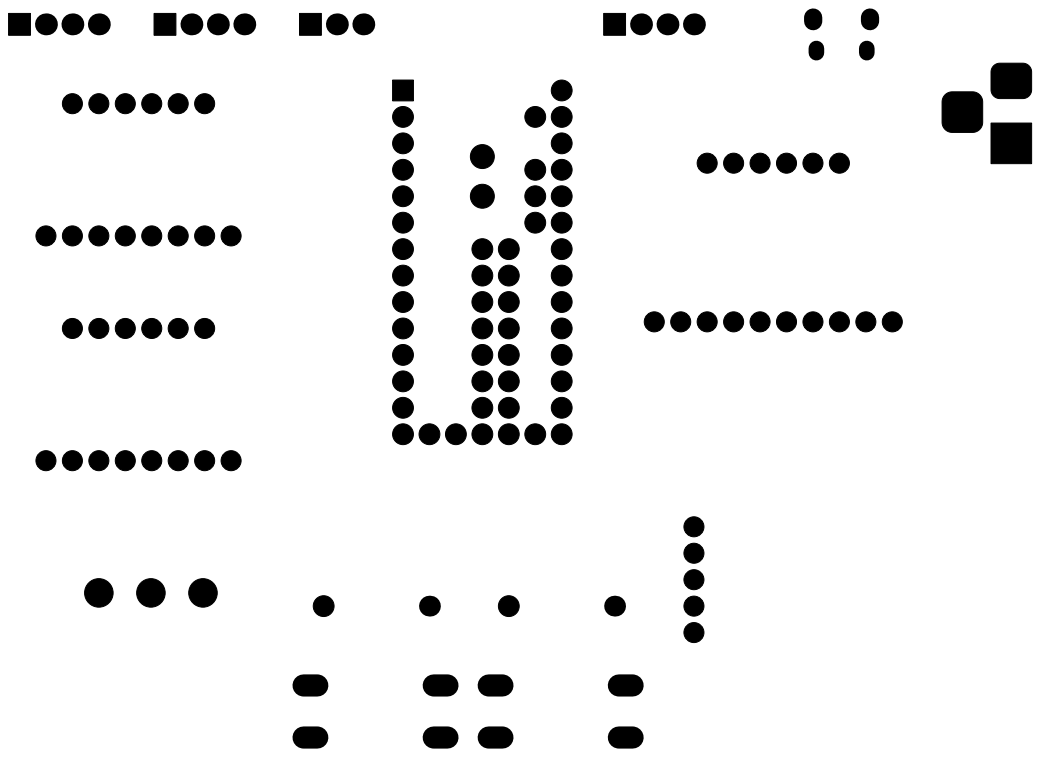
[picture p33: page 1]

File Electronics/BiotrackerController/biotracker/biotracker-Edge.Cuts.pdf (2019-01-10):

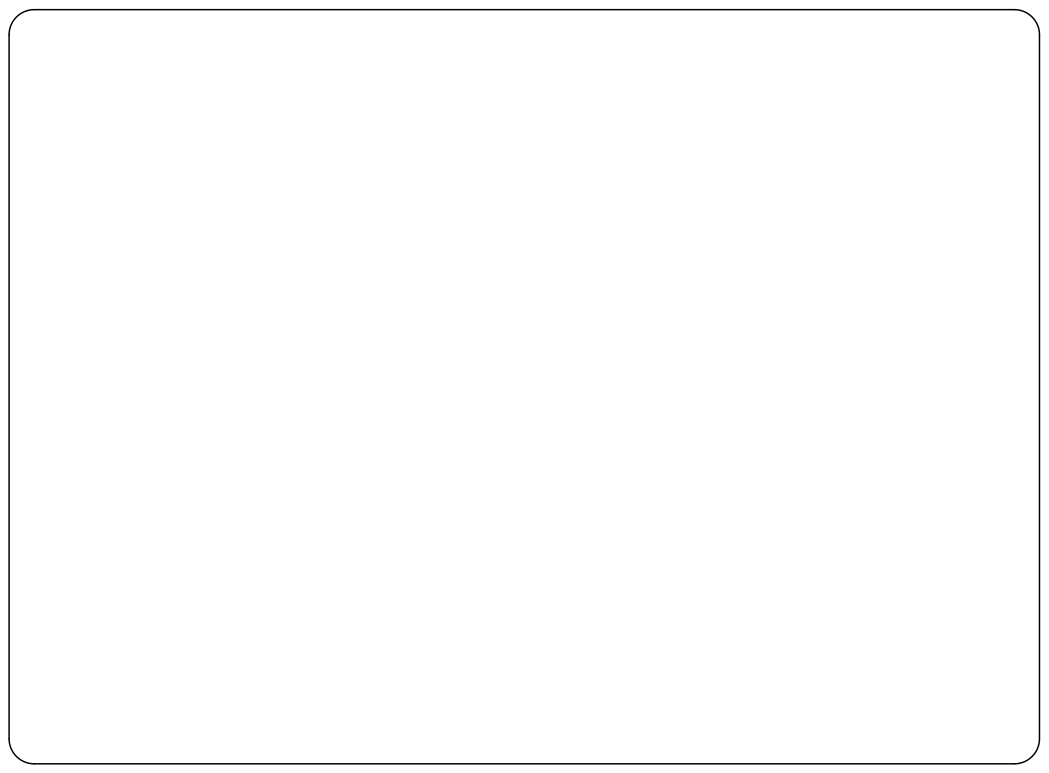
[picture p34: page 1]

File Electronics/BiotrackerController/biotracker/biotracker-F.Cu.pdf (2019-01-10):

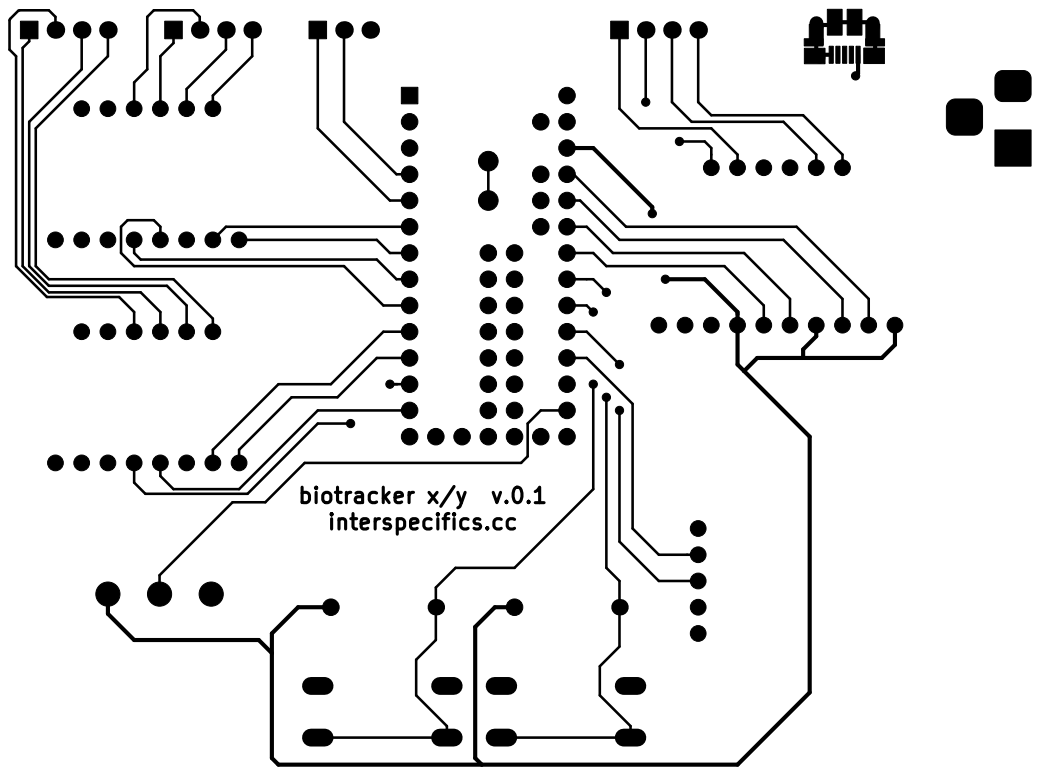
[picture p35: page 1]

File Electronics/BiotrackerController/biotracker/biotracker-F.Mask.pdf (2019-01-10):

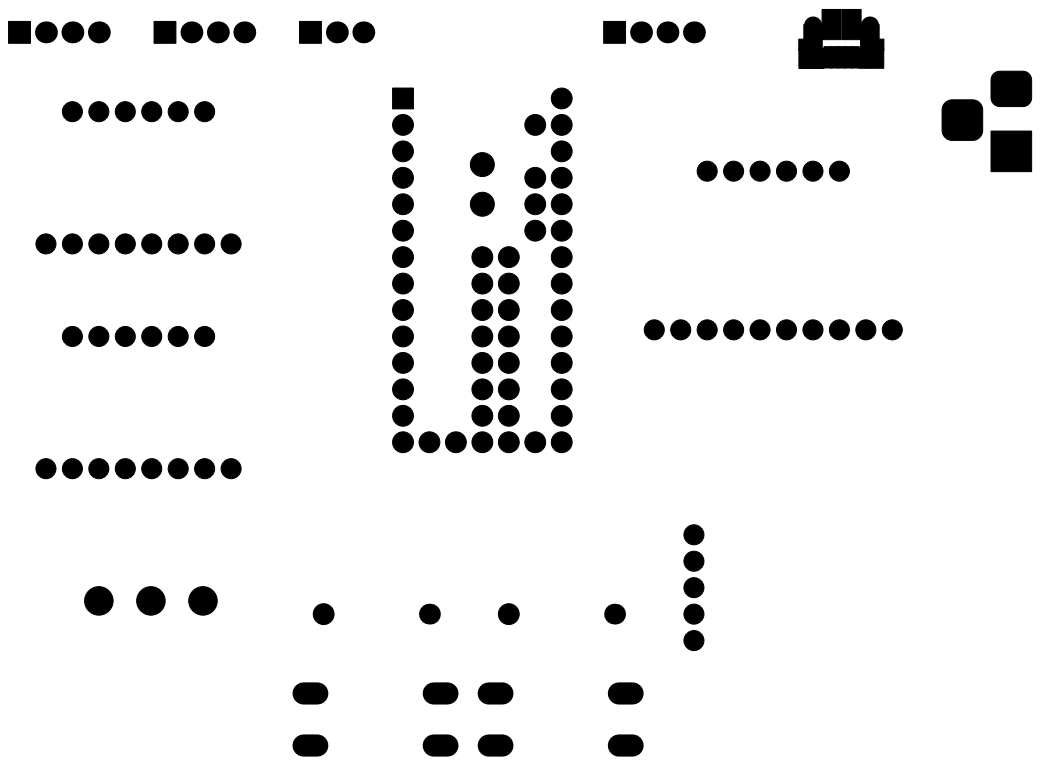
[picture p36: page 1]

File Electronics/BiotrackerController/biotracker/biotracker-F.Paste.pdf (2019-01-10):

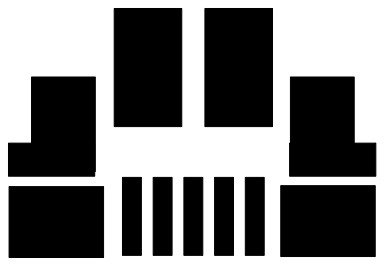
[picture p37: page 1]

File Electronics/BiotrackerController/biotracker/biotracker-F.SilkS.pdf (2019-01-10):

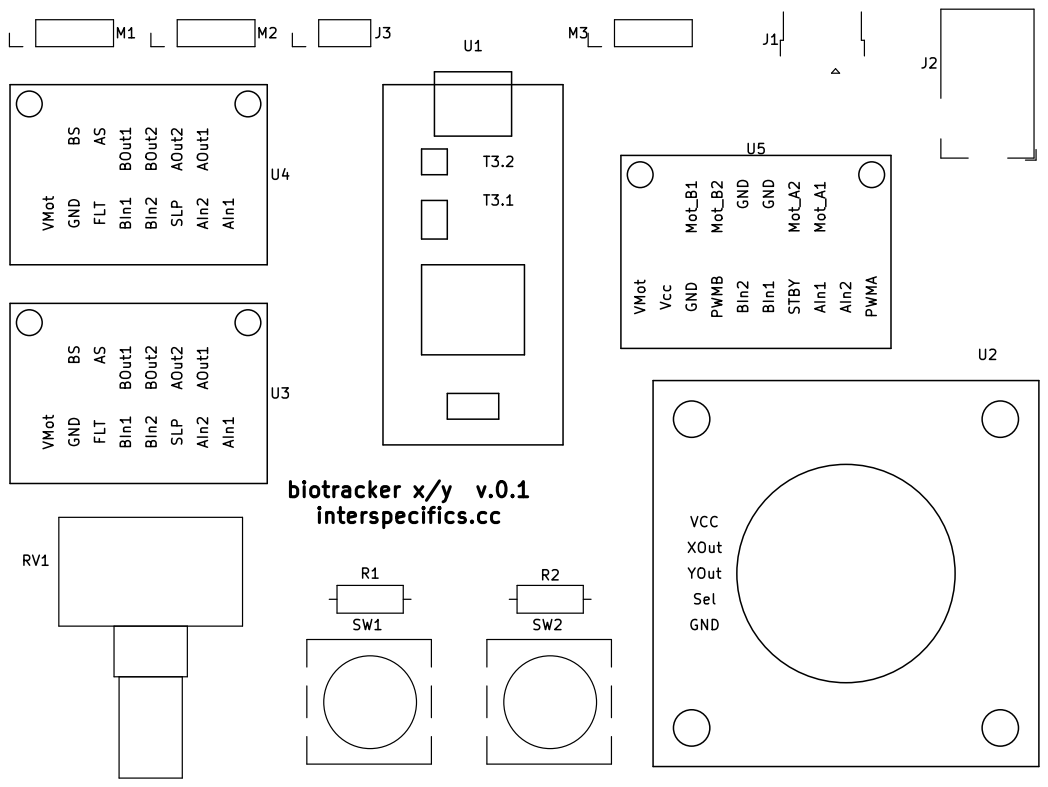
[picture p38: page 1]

Sel YOut XOut VCC

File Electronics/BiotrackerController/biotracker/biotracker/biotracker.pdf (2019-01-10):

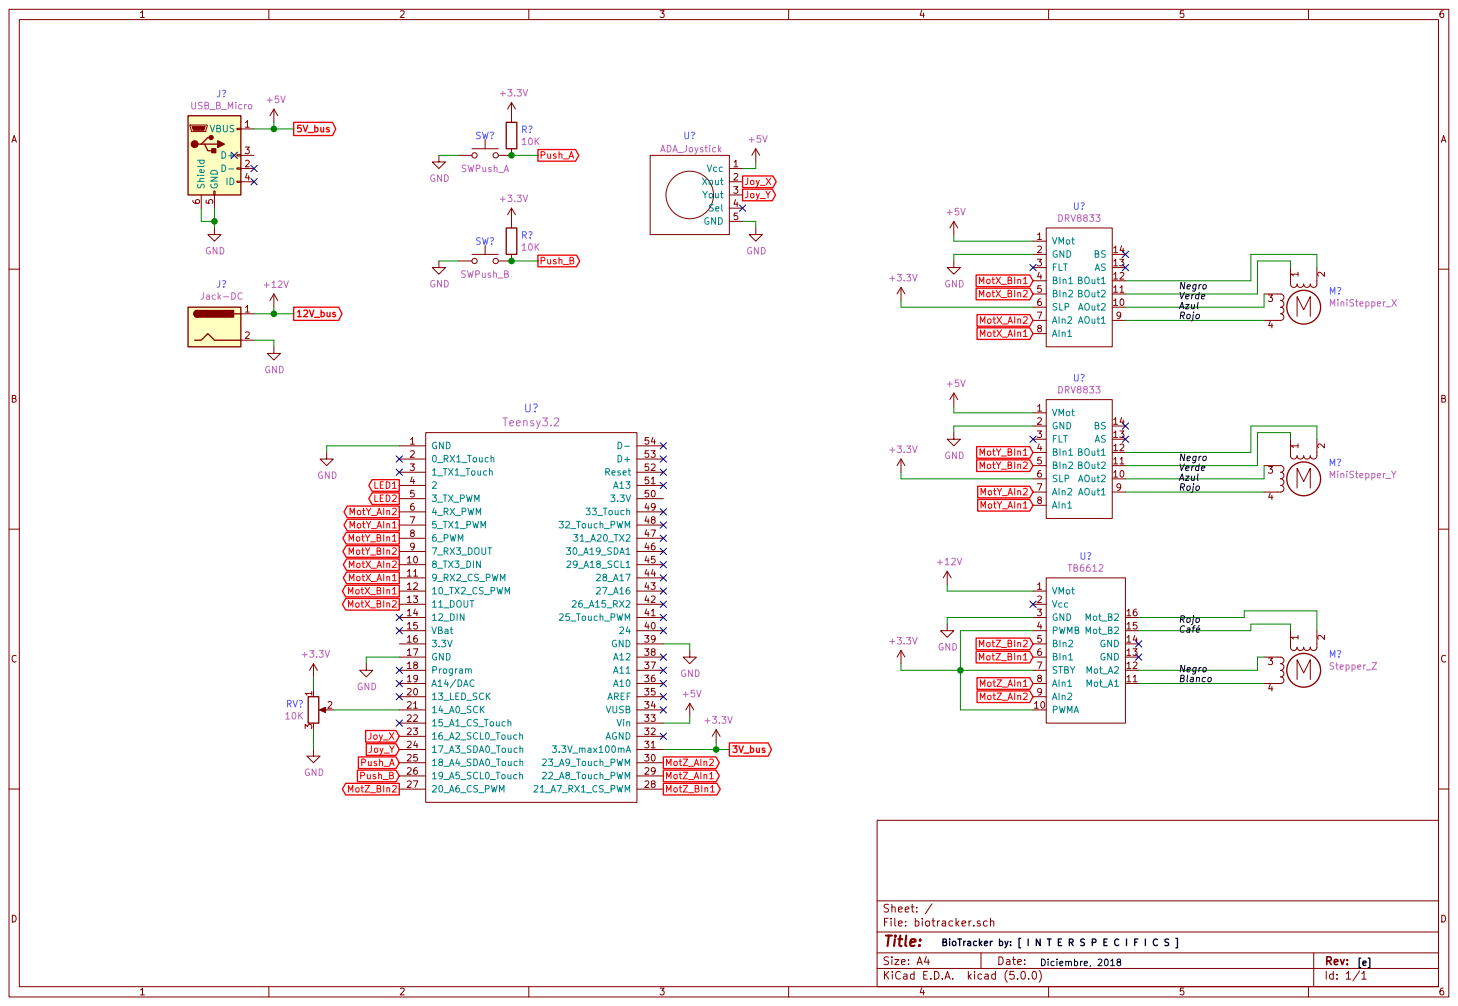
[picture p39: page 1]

Negro Verde Azul Rojo

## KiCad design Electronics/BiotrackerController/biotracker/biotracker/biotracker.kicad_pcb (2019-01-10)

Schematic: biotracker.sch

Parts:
J1: USB_B_Micro; USB_Micro-B_Amphenol_10103594-0001LF_Horizontal
J2: Jack-DC; BarrelJack_Horizontal
J3: Conn_01x03_Male; PinHeader_1x03_P2.54mm_Vertical
M1: MiniStepper_X; PinHeader_1x04_P2.54mm_Vertical
M2: MiniStepper_Y; PinHeader_1x04_P2.54mm_Vertical
M3: Stepper_Z; PinHeader_1x04_P2.54mm_Vertical
R1, R2: 10K; R_Axial_DIN0207_L6.3mm_D2.5mm_P10.16mm_Horizontal
RV1: 10K; Potentiometer_Alps_RK163_Single_Horizontal
SW1: SWPush_A; SW_PUSH-12mm
SW2: SWPush_B; SW_PUSH-12mm
U1: Teensy3.2; Teensy30_31_32_LC
U2: ADA_Joystick; ADA_joystick
U3, U4: DRV8833; ADA_DRV8833
U5: TB6612; ADA_TB6612

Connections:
3V_bus: R1.1, R2.1, RV1.1, U1.31, U3.6, U4.6, U5.4, U5.7, U5.10
5V_bus: J1.1, U1.33, U2.1, U3.1, U4.1
12V_bus: J2.1, U5.1
GND: J1.5, J1.6, J2.2, J3.3, RV1.3, SW1.1, SW2.1, U1.1, U2.5, U3.2, U4.2, U5.3
Joy_X: U1.23, U2.2
Joy_Y: U1.24, U2.3
LED1: J3.2, U1.4
LED2: J3.1, U1.5
MotX_AIn1: U1.11, U3.8
MotX_AIn2: U1.10, U3.7
MotX_BIn1: U1.12, U3.4
MotX_BIn2: U1.13, U3.5
MotY_AIn1: U1.7, U4.8
MotY_AIn2: U1.6, U4.7
MotY_BIn1: U1.8, U4.4
MotY_BIn2: U1.9, U4.5
MotZ_AIn1: U1.29, U5.8
MotZ_AIn2: U1.30, U5.9
MotZ_BIn1: U1.28, U5.6
MotZ_BIn2: U1.27, U5.5
unnamed: M1.1, U3.11
unnamed: M1.2, U3.12
unnamed: M1.3, U3.10
unnamed: M1.4, U3.9
unnamed: M2.1, U4.11
unnamed: M2.2, U4.12
unnamed: M2.3, U4.10
unnamed: M2.4, U4.9
unnamed: M3.1, U5.15
unnamed: M3.2, U5.16
unnamed: M3.3, U5.12
unnamed: M3.4, U5.11
unnamed: RV1.2, U1.21
Push_A: R1.2, SW1.2, U1.25
Push_B: R2.2, SW2.2, U1.26

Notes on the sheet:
Negro Verde Azul Rojo
Rojo Café Negro Blanco
3Axis BioTracker by [ I N T E R S P E C I F I C S ]
2018.12
[e] 1.0

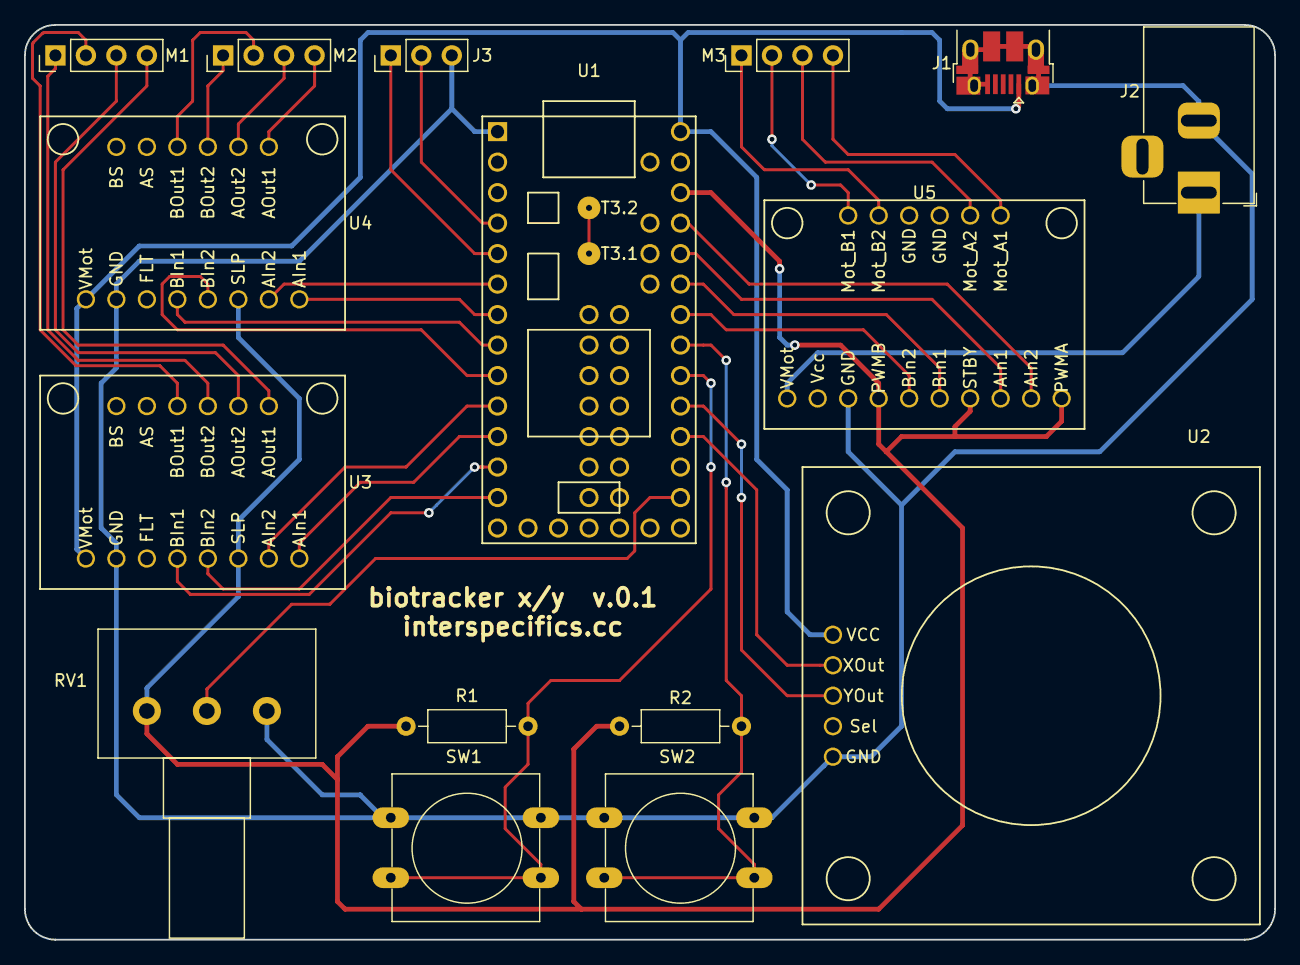
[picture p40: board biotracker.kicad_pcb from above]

Board: 2 copper layers, 104.1 x 76.2 mm, 16 parts (0 on the bottom side), 35 nets.

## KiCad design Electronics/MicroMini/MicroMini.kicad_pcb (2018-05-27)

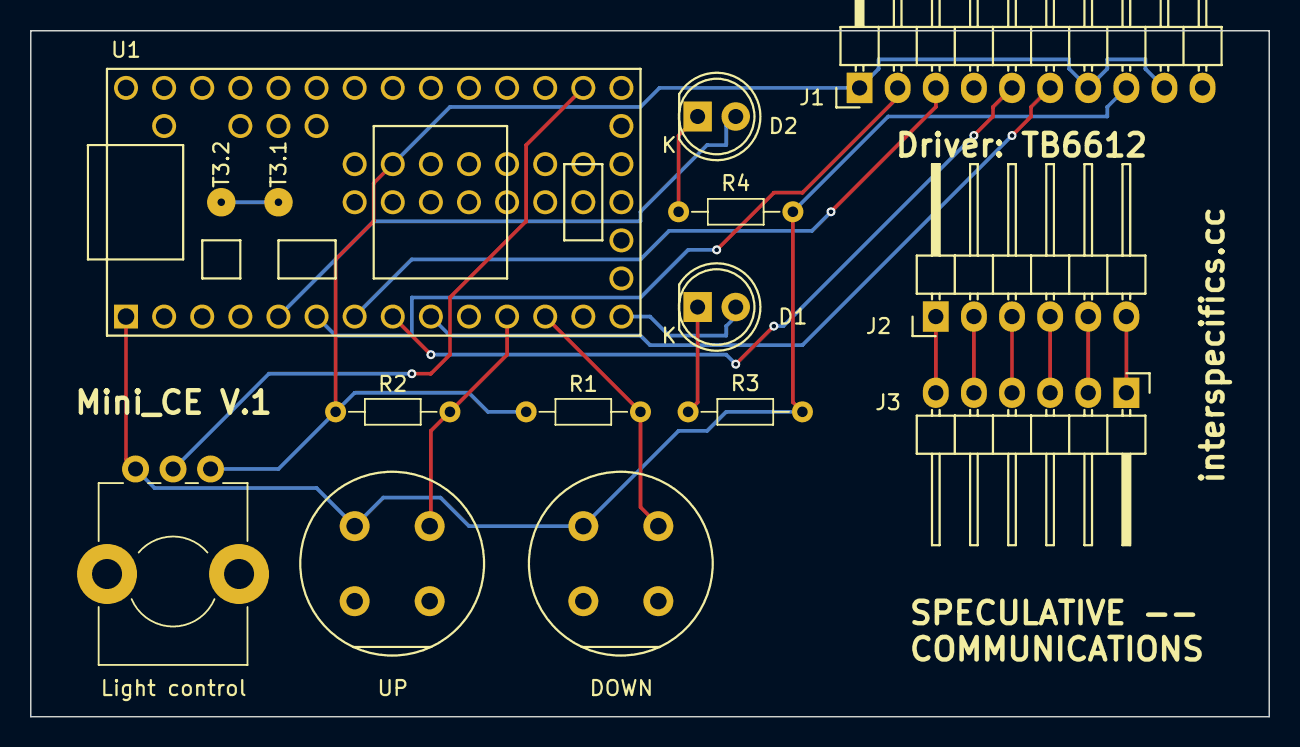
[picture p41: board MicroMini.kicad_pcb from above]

Board: 2 copper layers, 82.6 x 45.7 mm, 13 parts (0 on the bottom side), 19 nets.

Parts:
D1, D2: LED; LED-5MM
DOWN: SW_Push; Push_E-Switch_KS01Q01
J1: Conn_01x10; Pin_Header_Angled_1x10
J2, J3: Conn_01x06; Pin_Header_Angled_1x06
Light control: POT; Potentiometer_Alps_RK09K_Horizontal
R1, R2: 10k; R_Axial_DIN0204_L3.6mm_D1.6mm_P7.62mm_Horizontal
R3, R4: R; R_Axial_DIN0204_L3.6mm_D1.6mm_P7.62mm_Horizontal
U1: Teensy3.2; Teensy30_31_32_LC
UP: SW_Push; Push_E-Switch_KS01Q01

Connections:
GND: DOWN.1, J1.8, Light control.1, R3.1, R4.1, U1.1, UP.1
unnamed: D1.1, R3.2
unnamed: D1.2, U1.14
unnamed: D2.1, R4.2
unnamed: D2.2, U1.5
unnamed: J1.1, J1.7, J1.9, Light control.3, R1.1, R2.1, U1.50
unnamed: J1.2, U1.6
unnamed: J1.3, U1.7
unnamed: J1.5, U1.8
unnamed: J1.6, U1.9
unnamed: J2.1, J3.6
unnamed: J2.2, J3.5
unnamed: J2.3, J3.4
unnamed: J2.4, J3.3
unnamed: J2.5, J3.2
unnamed: J2.6, J3.1
unnamed: DOWN.2, R1.2, U1.12
unnamed: R2.2, U1.11, UP.2
unnamed: Light control.2, U1.21

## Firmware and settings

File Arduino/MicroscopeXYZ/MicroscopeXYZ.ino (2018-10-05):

#include <Stepper.h>
const int buttonFor = A4;
const int buttonBack = A5;

int led = 3;
int led2 = 2;
int pot = A0; //Light control
int Yout = A3;
int Xout = A2;

int delayval = 500; // delay for half a second

const int stepsPerRevolution = 200;  // change this to fit the number of steps per revolution
// for your motor

// initialize the stepper library on pins 4 through 7:
Stepper myStepper1(stepsPerRevolution, 4, 5, 6, 7);
Stepper myStepper2(stepsPerRevolution, 8, 9, 10, 11);
Stepper myStepper(stepsPerRevolution, 22, 23, 21, 20);


int buttonState1 = 0;
int buttonState2 = 0;
int potValue = 0;
int Xvalue = 0;
int Yvalue = 0;
int Xwrite;
int Ywrite;
int writeValue;
int stepCount = 0;         // number of steps the motor has taken



void setup() {
  // initialize the serial port:
  Serial.begin(9600);
  pinMode(buttonFor, INPUT);
  pinMode(buttonBack, INPUT);
  pinMode(pot, INPUT);
  pinMode(Yout, INPUT);
  pinMode(Xout, INPUT);
  pinMode(led, OUTPUT);
  pinMode(led2, OUTPUT);

  myStepper.setSpeed(30);
  myStepper1.setSpeed(60);
  myStepper2.setSpeed(60);
}

void loop() {

//_____________xy control

Xvalue = analogRead(Xout);
Yvalue = analogRead(Yout);

//____________ led brightness
potValue = analogRead(pot);
writeValue = (255./1023) *potValue;

analogWrite(led, writeValue);
analogWrite(led2, writeValue);


//---- x control

if (Xvalue > 770 && Xvalue < 850) {
  myStepper1.step(0);
  myStepper2.step(0);
Serial.println("myStepper1: stop");

}


if (Xvalue > 850 && Xvalue < 1023) {
   myStepper1.step(1);
   myStepper2.step(1);
       Serial.println(stepCount);
       stepCount++;
 }

else {
 myStepper1.step(0);
 myStepper2.step(0);
Serial.println("myStepper1: stop");
}


if (Xvalue < 400 && Xvalue < 600) {
  myStepper1.step(-1);
  myStepper2.step(-1);
       Serial.print("myStepper1: atras");
       stepCount++;
}


else {
 myStepper1.step(0);
  myStepper2.step(0);
Serial.println("myStepper1: stop");
}


 if (Xvalue > 770   && Xvalue < 850 ){
  myStepper1.step(0);
  myStepper2.step(0);
  Serial.println("myStepper1: stop");
}

/////// ------- Y control


if (Yvalue > 740 && Yvalue < 850) {
  myStepper2.step(0);
  myStepper1.step(0);
Serial.println("myStepper2: stop");

}


if (Yvalue > 850 && Yvalue < 1023) {
   myStepper2.step(1);
   myStepper1.step(-1);
       Serial.println(stepCount);
       stepCount++;
 }

else {
 myStepper2.step(0);
 myStepper1.step(0);
Serial.println("myStepper2: stop");
}


if (Yvalue < 400 && Xvalue < 600) {
  myStepper2.step(-1);
  myStepper1.step(1);
       Serial.print("myStepper2: atras");
       stepCount++;
}


else {
 myStepper2.step(0);
 myStepper1.step(0);
Serial.println("myStepper2: stop");
}


 if (Yvalue > 740   && Xvalue < 850 ){
  myStepper2.step(0);
   myStepper1.step(0);
  Serial.println("myStepper2: stop");
}


    buttonState1 = digitalRead(buttonFor);
    buttonState2 = digitalRead(buttonBack);

//_____________controller for number of stpes ( 400 steps per click )


      if (buttonState1 == LOW) {
        myStepper.step(1);
        Serial.print("adelante:");
        Serial.println(stepCount);
        stepCount++;
      }

      else {
        myStepper.step(0);
        Serial.println("stop");
      }

      if (buttonState2 == LOW) {
        myStepper.step(-1);
        Serial.print("atras:");
        Serial.println(stepCount);
        stepCount++;
      }

      else {
        myStepper.step(0);
        Serial.println("stop");
      }


//___________controller for number of stpes ( 1 step per click )


      if (buttonState1 == LOW) {
        myStepper.step(1);
        Serial.print("adelante:");
        Serial.println(stepCount);
        stepCount++;
      }


      else {
        myStepper.step(0);
        Serial.println("stop");
      }

      if (buttonState2 == LOW) {
        myStepper.step(-1);
        Serial.print("atras:");
        Serial.println(stepCount);
        stepCount++;
      }

      else {
        // turn LED off:
        myStepper.step(0);
        Serial.println("stop");
      }

    }

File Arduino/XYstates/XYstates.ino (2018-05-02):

  int analogValue = A3;   
  int analogValue1 = A2; 

void setup() {

  Serial.begin(9600);
}

void loop() {

  analogValue = analogRead(3);
  analogValue1 = analogRead(2);
 
  


  Serial.print(analogValue, DEC);         
  Serial.print("\t A:");              
  Serial.print(analogValue1, DEC);    
  Serial.print("\t B:");                 
  Serial.println();                 

  // delay 10 milliseconds before the next reading:
  delay(10);
}

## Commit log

2017-06-14 load camera
2017-07-19 optic flow
    tools
2017-07-22 visuals
    sketcj para OFX
2017-07-25 controlador de stage z
2017-07-25 change camera input
2017-07-25 led control
2017-09-06 openscad and STL files for LED and corner cube
    [CE_LEDholderV2.scad, CE_LEDholderV2.stl, CE_corner_openbeam.scad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]
2018-02-25 optics folder
    [CE_RPIcam_cover.stl, CE_cam_adapter.stl, CE_lens_holder_ring.stl]
2018-05-27 circuit for controll z and code xy
    [MicroMini-B.Cu.gbr, MicroMini-B.Mask.gbr, MicroMini-B.SilkS.gbr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]
2018-12-20 CE_sound+light
    Update con el software de las luces reactivas
2019-01-10 files for the XY version complete
    [Base inferior.stl, Base superior.stl, Bearing Mount Left Bottom.STL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]
2019-01-10 biotracker xy full controller
    [biotracker.kicad_pcb, biotracker.sch, biotracker_tracks.kicad_pcb]
2019-01-20 added original openscad file for optics
    [CE_3D_Optics_V2_1.scad, CE_RPIcam_cover.stl, CE_cam_adapter.stl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]
2019-01-20 deleted replicated files
    [CE_RPIcam_cover.stl, CE_cam_adapter.stl, CE_lens_holder_ring.stl]
2019-07-25 new adapter for RPI cam
    [CE_3D_Optics_V2_1.scad]
2019-07-27 new adapter for c270 webcam and adapter for doublet lens
    [CE_3D_Optics_V2_1.scad, CE_c270_camera_adapter.stl, logitech_c270.scad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]
